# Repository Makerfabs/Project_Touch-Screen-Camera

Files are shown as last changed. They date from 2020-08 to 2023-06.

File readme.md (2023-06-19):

# ESP32 3.5" TFT Touch with Camera

```c++
/*
Version:		V6.2
Author:			Vincent
Create Date:	2020/8/19
Note:
	V6.2 : Change Wiki link.
	V6.1 : Update firmware add camera config faq.
	V6.0 : Add WiFi bulletin board demo
	V5.0 : Add Environment Expansion Board
	V4.1 : Add 1 show example.
	V4.0 : Add 4 show example.
	V3.4 : Thanks Lovyan03's change. Greatly speed up the rendering process.
	V3.3 : Change UI direction.
	V3.2 : Added the ability to upload photos to PC through WiFi. 
	V3.1 : Replace the picture with the new hardware.
	V3.0 : Delete many useless code. Add FAQ.
	V2.0 : Change ILI9488 driver,use LovyanGFX lib.Ten times faster than before!!!
	
*/
```
[ESP32 Touch Camera](https://www.youtube.com/watch?v=zWUy4gcwMs4&feature=youtu.be)

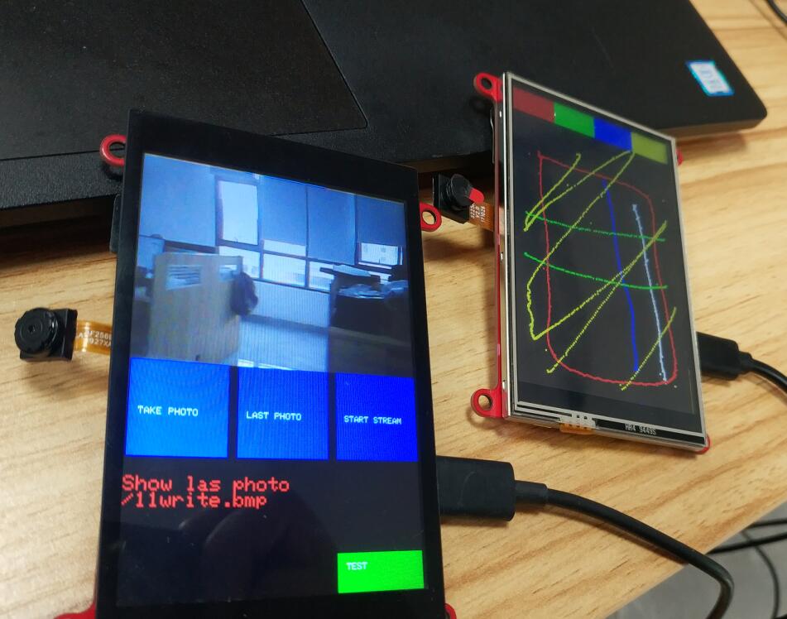
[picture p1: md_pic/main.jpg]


[toc]

# Makerfabs

[Makerfabs home page](https://www.makerfabs.com/)

[Makerfabs Wiki](https://wiki.makerfabs.com/)

# ESP32 3.5" TFT Touch with Camera

## Introduce

Product link ：[ ESP32 Touch Camera(Resistive)](https://www.makerfabs.com/esp32-3.5-inch-tft-touch-resistive-with-camera.html) 

Product link ：[ ESP32 Touch Camera(Capacitive)](https://www.makerfabs.com/esp32-3.5-inch-tft-touch-capacitive-with-camera.html) 

Wiki link ：[ESP32 3.5" TFT Touch with Camera](https://wiki.makerfabs.com/ESP32_3.5_TFT_Touch_with_Camera.html) 

The ESP32 Touch Camera use ILI9488 screen, which comes with resistive or capacitive screens. Have an OV2640 camera and SD card slot. It can be used as a webcam, an electronic album, or a digital camera. Support for Arduino and MicroPython. 

## Feature

- Integrated ESP32 2.4G WiFi and Bluetooth.
- Micro SD card slot on board.
- Input 5.0V Type-C USB .
- OV2640 is a 1/4 inch CMOS UXGA (1632*1232) image sensor manufactured by OmniVision.
- LCD 3.5 inch Amorphous-TFT-LCD (Thin Film Transistor Liquid Crystal Display) for mobile-phone or handy electrical equipments.
- NS2009 is A 4-wire resistive touch screen control circuit with I2C interface, which contains A 12-bit resolution A/D converter.

- The FT6X36 Series ICs are single-chip capacitive touch panel controller IC with a built-in 16 bit enhanced Micro-controller unit (MCU).

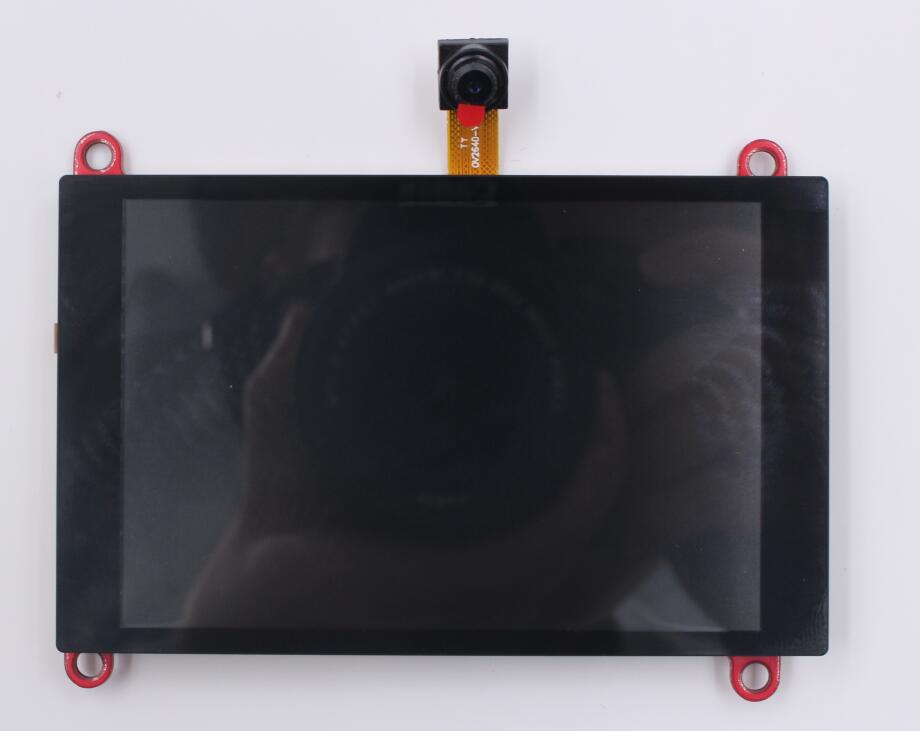
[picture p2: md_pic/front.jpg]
front


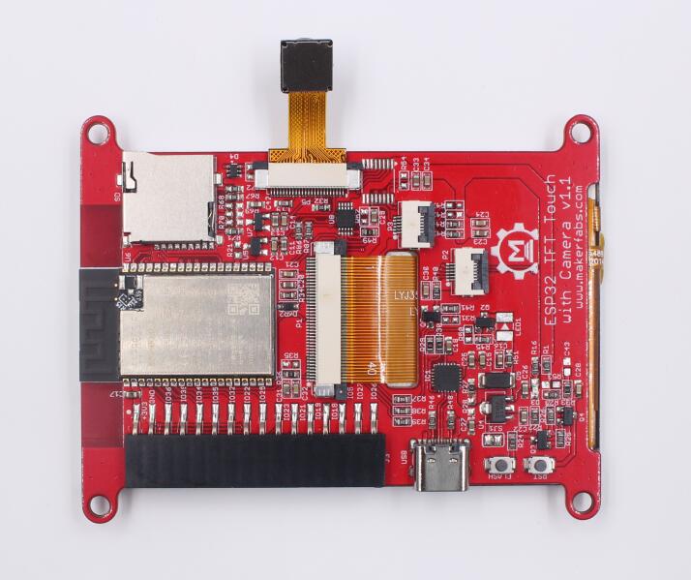
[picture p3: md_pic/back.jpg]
back


# Project

## Related projects

[ESP32 2048 GAME](https://github.com/Makerfabs/Project_ESP32-2048GAME)

Implement a 2048 game on "ESP32 Touch Camera". 

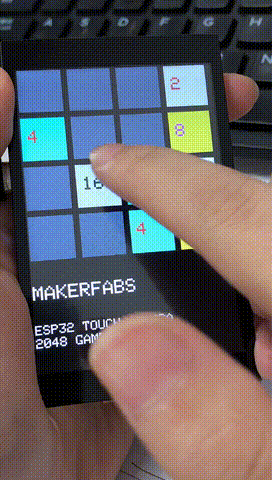
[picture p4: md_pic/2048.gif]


[ESP32 Flappy Bird](https://github.com/Makerfabs/Project_ESP32-Flappy-Bird)

Implement a Flappy Bird game on "ESP32 Touch Camera". 

Flappy

## Project introduction

Four projects were implemented : "Camera", "Touch_Draw", "SD2TFT" and "Receive WiFi Video".

### Camera_V2

- Take photos with OV2640 camera and preview in real-time on TFT screen.
- You can save photos to an SD card.
- Photos taken can be viewed through the TFT screen.

### Touch_Draw_V2

- Use your hand or stylus (resistance screen) to draw on the screen.

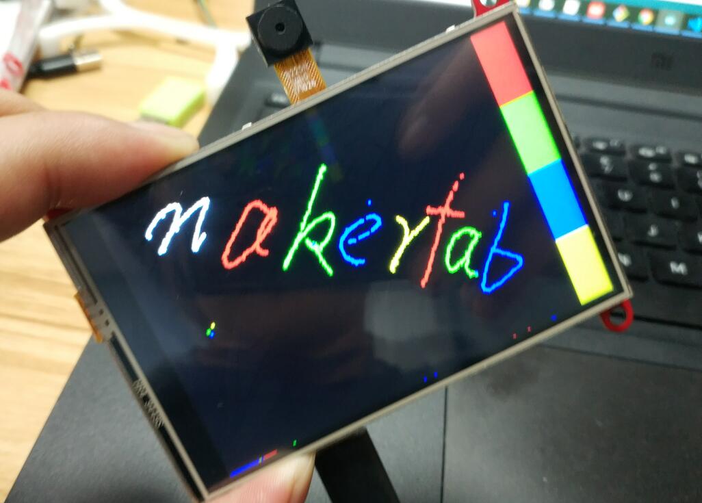
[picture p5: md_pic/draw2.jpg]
Touch_Draw_V2


### SD2TFT 

- Display pictures from SD card.
- Loop back the images in the SD card.

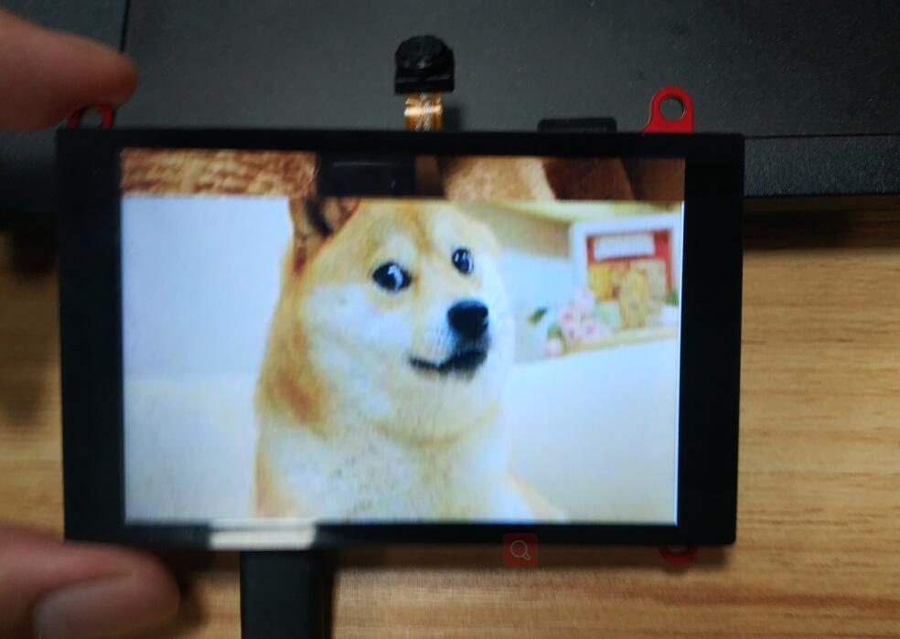
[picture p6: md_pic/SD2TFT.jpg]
SD2TFT


### Receive WiFi Video

Transmit the contents of the monitor to the TFT screen via Wifi.A host computer software is provided to box select the areas of the screen that need to be transferred.

Change from [MakePython ESP32 Color LCD で 動画をWiFi受信](https://homemadegarbage.com/makerfabs05)

- Upload file : "/Project_Touch-Screen-Camra/ESP32_ScreenShotReceiver-master/ScreenShotReceiver/ScreenShotReceiver.ino"
- Open "/Project_Touch-Screen-Camra/ESP32_ScreenShotReceiver-master/ScreenShotSender.exe"
- Input IP on the screen.

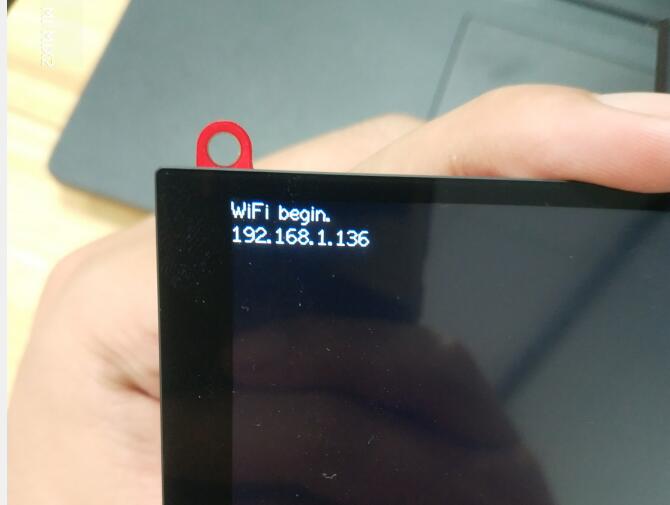
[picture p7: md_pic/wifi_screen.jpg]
wifiscreen


- Push connect.
- Start share your screen to TFT.

wifi_screen

## Compiler Options

**If you have any questions，such as how to install the development board, how to download the code, how to install the library. Please refer to :[Makerfabs_FAQ](https://github.com/Makerfabs/Makerfabs_FAQ)**

- Install board : ESP32 , select ESP32 version 1.0.6!!!!!!! After 2.0.0 version can't run successfully.
- **2022/4/28 Add：I don't know which libraries I updated, 1.0.6 compiles but doesn't drive the camera properly, rolling back the ESP32 version to 1.0.5 works fine.**
- Install library : LovyanGFX library. (SD2TFT is use a different GFX lib, depend on Adafruit_GFX. )
- Edit the code based on the touch screen. If you use resistive screen, choice NS2009_TOUCH. If you use capacitive screen, choice FT6236_TOUCH.

```c++
#define NS2009_TOUCH        //Resistive screen driver    
//#define FT6236_TOUCH      //Capacitive screen driver

#ifdef NS2009_TOUCH
#include "NS2009.h"
const int i2c_touch_addr = NS2009_ADDR;
#endif

#ifdef FT6236_TOUCH
#include "FT6236.h"
const int i2c_touch_addr = TOUCH_I2C_ADD;
#endif

```

- Upload codes, select "ESP32 Wrover Module" and "Huge APP"

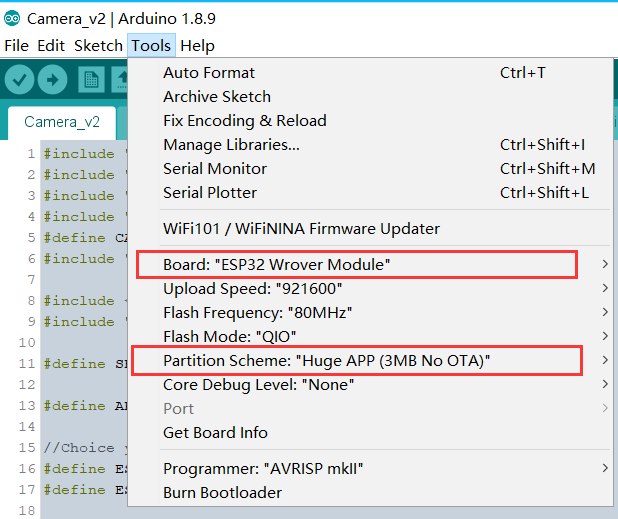
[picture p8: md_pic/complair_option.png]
complair-option


- Insert a Micro SD card into ESP32 Touch Camera.

## How To Use ESP32 Touch Camera

- Open the serial port monitor after uploading the code.
- Serial port will return initialization information, pay attention to see if there is any error.

```txt
14:48:49.096 -> ets Jun  8 2016 00:22:57
14:48:49.096 -> 
14:48:49.096 -> rst:0x1 (POWERON_RESET),boot:0x17 (SPI_FAST_FLASH_BOOT)
14:48:49.096 -> configsip: 0, SPIWP:0xee
14:48:49.096 -> clk_drv:0x00,q_drv:0x00,d_drv:0x00,cs0_drv:0x00,hd_drv:0x00,wp_drv:0x00
14:48:49.096 -> mode:DIO, clock div:1
14:48:49.096 -> load:0x3fff0018,len:4
14:48:49.096 -> load:0x3fff001c,len:1100
14:48:49.096 -> load:0x40078000,len:9232
14:48:49.096 -> load:0x40080400,len:6400
14:48:49.096 -> entry 0x400806a8
14:48:50.641 -> ILI9488 Test!
14:48:50.641 -> I2C device found at address 0x38  !
14:48:50.675 -> Card Mount Successed
14:48:50.675 -> SD init over.
14:48:51.397 -> TFT init over.
14:49:10.660 -> Image name：/0write.bmp
14:49:13.859 -> Image name：/1write.bmp

```

- If the SD card cannot be mounted on return, you need to re-insert the SD card.
- If everything is normal, the camera interface will be displayed.

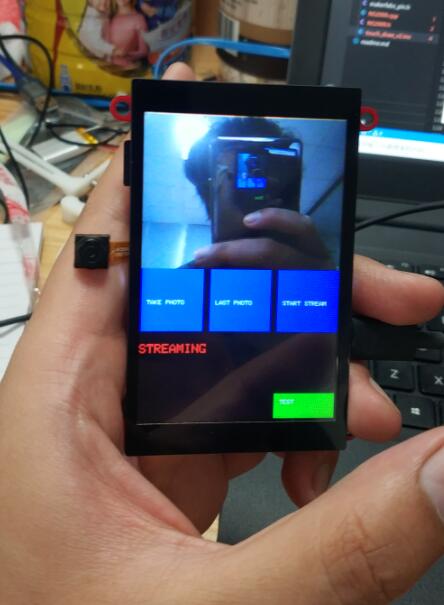
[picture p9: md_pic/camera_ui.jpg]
camera_ui


- Press the camera button to take photos automatically.
- Click on the previous photo to show the last photo saved on the SD card.

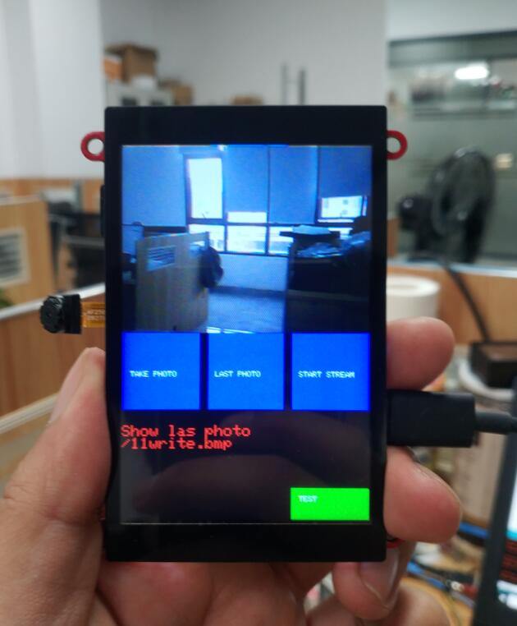
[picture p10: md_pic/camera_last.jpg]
camera_last


- Pressing to show the last photo will stop the camera acquisition. To restore the preview, press open Stream.
- Restore stream mode to take photos again.
- You can unplug your SD card and plug it into your computer to view your photos.

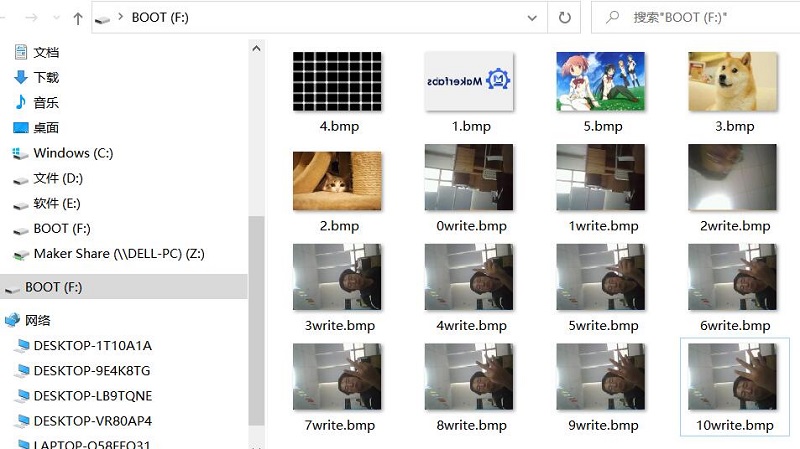
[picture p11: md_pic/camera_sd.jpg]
camera_sd


## V3.2 Upload photos via WiFi
Added the function of sending photos to PC via HTTP protocol by post method.
- Remove comments before WIFI_MODE

```c++
#define WIFI_MODE
```
- Set the wifi ssid and password.

```c++
// wait for WiFi connection
WiFi.mode(WIFI_STA);
WiFi.begin("Makerfabs", "20160704");
```
- Upload code to ESP32 camera.
- Run the server.py  on PC side.(Make sure to run in the directory server.py, otherwise the upload path cannot be found.)

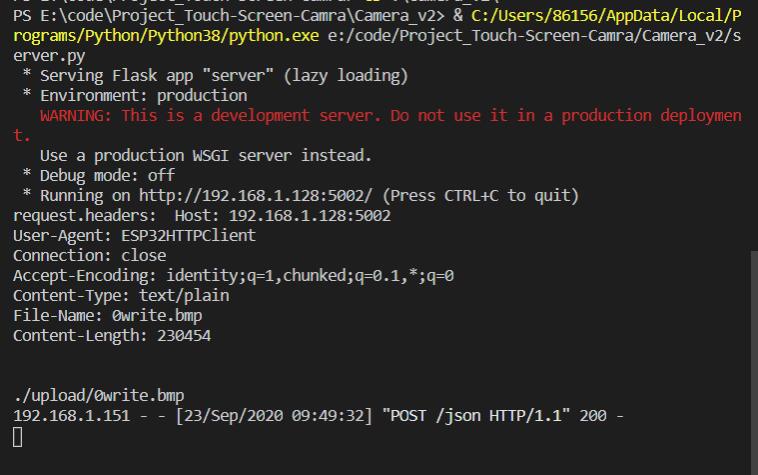
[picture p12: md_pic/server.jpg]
server

- Every time you click to show the last photo, it will be automatically uploaded.

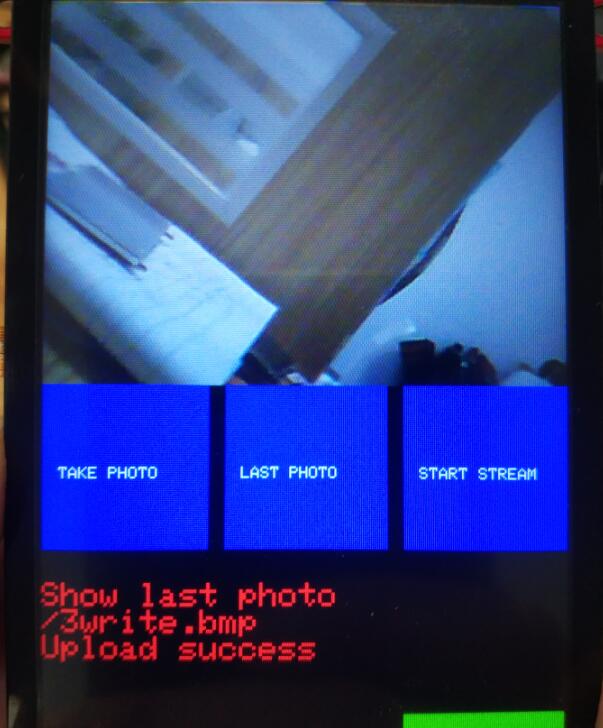
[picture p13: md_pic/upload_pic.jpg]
upload_pic

- In a few seconds, the picture will be uploaded to the Upload folder.
- V3.3  :  The UI has changed, but the functionality remains the same.

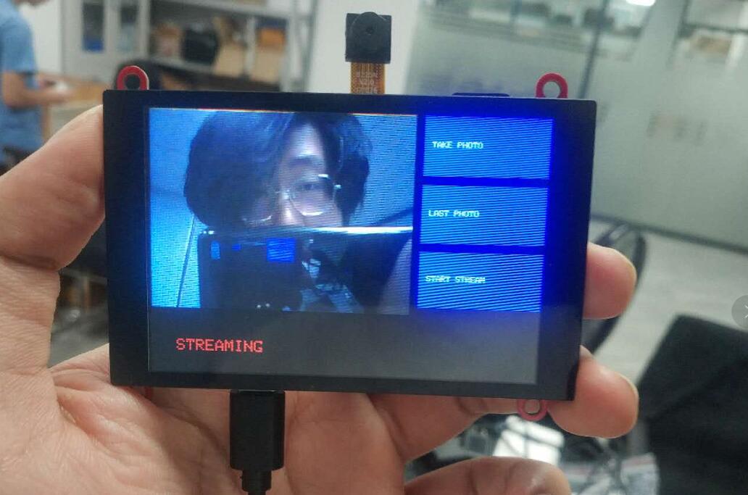
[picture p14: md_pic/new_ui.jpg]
new_ui


## V4.0 Show Example

Add 4 example in /Project_Touch-Screen-Camra/example

- Aht10 show
- HCSR04 meter
- Web button
- Wind speed show

These examples depend on TFT_eSPI library. You must set "User_Setup.h".
Set screen type.

```c++
// Only define one driver, the other ones must be commented out
//#define ILI9341_DRIVER
//#define ST7735_DRIVER      // Define additional parameters below for this display
//#define ILI9163_DRIVER     // Define additional parameters below for this display
//#define S6D02A1_DRIVER
//#define RPI_ILI9486_DRIVER // 20MHz maximum SPI
//#define HX8357D_DRIVER
//#define ILI9481_DRIVER
//#define ILI9486_DRIVER
#define ILI9488_DRIVER     // WARNING: Do not connect ILI9488 display SDO to MISO if other devices share the SPI bus (TFT SDO does NOT tristate when CS is high)
//#define ST7789_DRIVER      // Full configuration option, define additional parameters below for this display
//#define ST7789_2_DRIVER    // Minimal configuration option, define additional parameters below for this display

// For ST7789, ST7735, ILI9163 and GC9A01 ONLY, define the pixel width and height in portrait orientation
// #define TFT_WIDTH  80
// #define TFT_WIDTH  128
// #define TFT_WIDTH  172 // ST7789 172 x 320
//#define TFT_WIDTH  240 // ST7789 240 x 240 and 240 x 320
#define TFT_WIDTH  320
// #define TFT_HEIGHT 160
// #define TFT_HEIGHT 128
// #define TFT_HEIGHT 240 // ST7789 240 x 240
// #define TFT_HEIGHT 320 // ST7789 240 x 320
//#define TFT_HEIGHT 240 // GC9A01 240 x 240
#define TFT_HEIGHT 480

```
And set pins.

```c++
// For 3.5" 9488
// The hardware SPI can be mapped to any pins

#define TFT_MISO 12
#define TFT_MOSI 13
#define TFT_SCLK 14
#define TFT_CS   15  // Chip select control pin
#define TFT_DC    33  // Data Command control pin
#define TFT_RST   26  // Reset pin (could connect to RST pin)

```

## V4.1 Show Example

Add environment monitoring module demo.

- Line chart

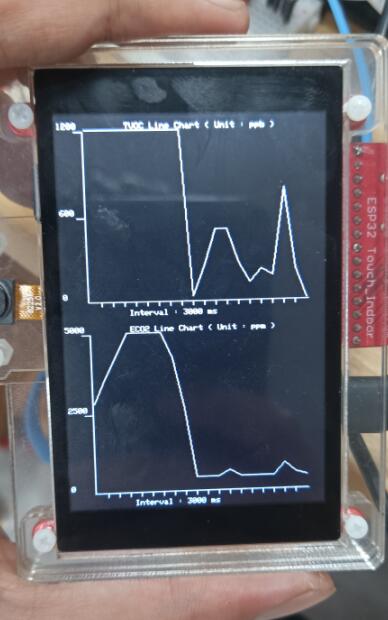
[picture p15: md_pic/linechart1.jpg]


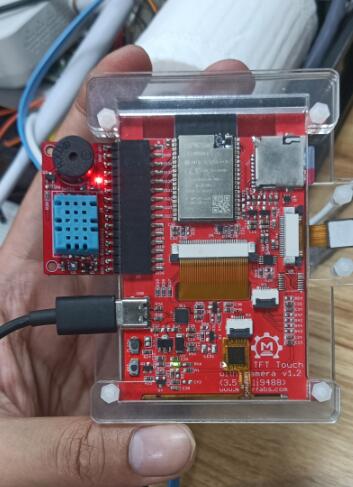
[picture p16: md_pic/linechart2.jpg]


## V6.0 WiFi bulletin board Demo

Added a WiFi bulletin board app. You can upload and browse files in the SD card through the web page. And the latest uploaded BMP or TXT display on the 3.5-inch screen.

- Library Install：[esp32-micro-sdcard](https://github.com/nhatuan84/esp32-micro-sdcard) and [esp32-webserver](https://github.com/nhatuan84/esp32-webserver)
- Upload .\example\wifi_img\wifi_img.ino
- Insert the SD card and power on.
- Enter the IP address on the screen in your browser.

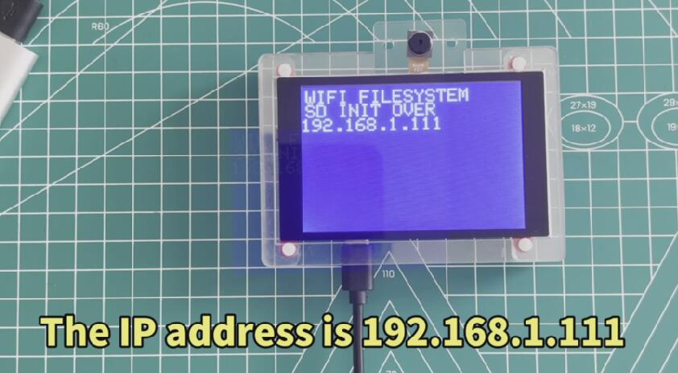
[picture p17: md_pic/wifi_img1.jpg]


- Select TXT or BMP to be uploaded. BMP must be 480 x 320 pixels, 24 bits.

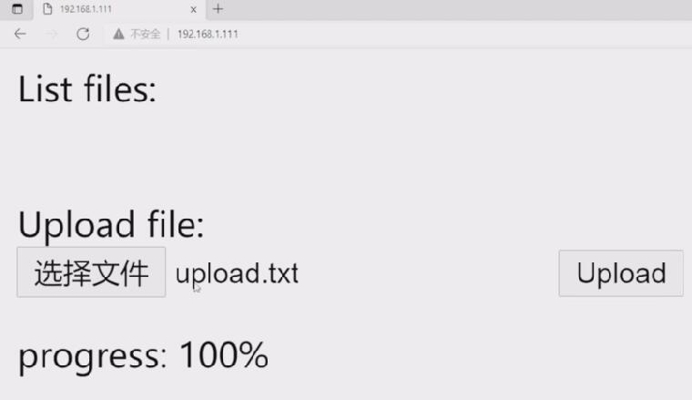
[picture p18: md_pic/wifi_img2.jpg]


- Upload.
- Wait seconds, the content is displayed on the screen.

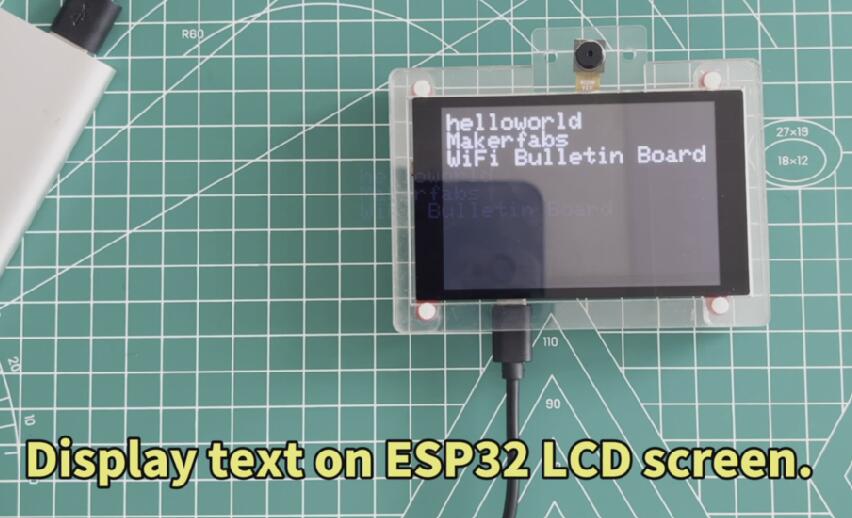
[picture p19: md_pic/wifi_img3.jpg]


## FAQ

### Q: Can't Upload!

A: Switch to a good USB cable. Poor USB cable quality can cause ESP32 to reboot or fail to upload. Open the serial monitor, observe serial port information.

### Q: The screen is white!

A: The SD card was not mounted successfully, so the program goes into an endless loop. Re-insert the SD card and restart it. Open the serial monitor,  The serial port will display the work log.

### Q: It doesn't show the picture that was just taken!

A: It may be that after shooting, the SD card was not in good contact, so it could not be stored in the SD card. Playback photos are read inside the SD card photos. Re-insert the SD card and restart it.

### Q: Other questions...

A: Re-insert the SD card and restart it. Can solve most problems. (laugh)

### Q: Camera direction wrong

A: Depending on the batch of purchased cameras, the picture may be inverted. You can configure the following functions.

Change set_vflip() param to flip camera or set_hmirror() to mirror image.

```c++
// Camera setting
void camera_init()
{
    // camera config
    
    //...

    sensor_t *s = esp_camera_sensor_get();
    // initial sensors are flipped vertically and colors are a bit saturated
    if (s->id.PID == OV2640_PID)
    {
        s->set_vflip(s, 0);   // vertical flip
        s->set_hmirror(s, 0); // Horizontal mirror

        s->set_brightness(s, 0); // up the blightness just a bit
        s->set_saturation(s, 1); // lower the saturation
    }
    // drop down frame size for higher initial frame rate
    s->set_framesize(s, FRAMESIZE_QVGA);

    show_log(2);
}
```

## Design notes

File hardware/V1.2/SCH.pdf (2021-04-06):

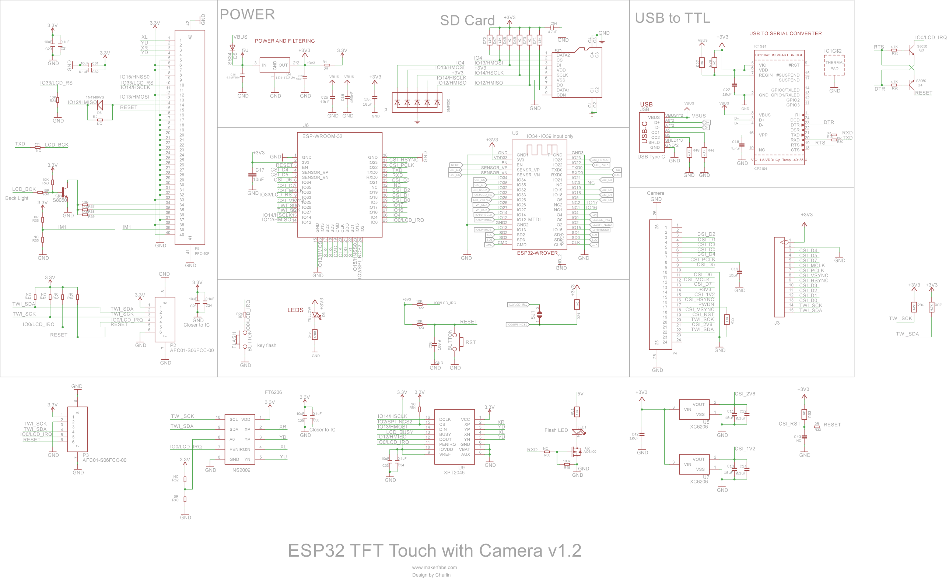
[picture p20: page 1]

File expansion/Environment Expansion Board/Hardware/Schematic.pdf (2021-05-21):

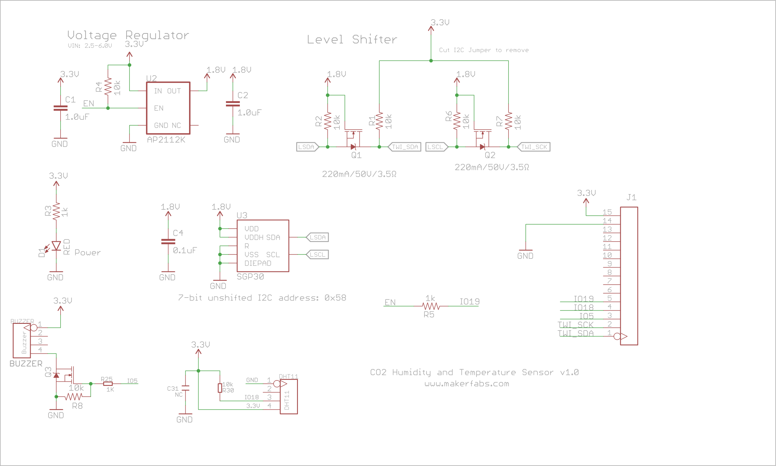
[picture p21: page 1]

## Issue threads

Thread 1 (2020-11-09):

How to buy products in China?

modi12jin, 2020-11-09:
Ask about non-technical topics, how can China buy your products?

Makerfabs, 2020-11-10:
Please contact sales: zeqing2012@makerfabs.com

发件人: modi12jin [mailto:notifications@github.com]
发送时间: 2020年11月9日 19:23
收件人: Makerfabs/Project_Touch-Screen-Camera
抄送: Subscribed
主题: [Makerfabs/Project_Touch-Screen-Camera] How to buy products in China? (#1)

Ask about non-technical topics, how can China buy your products?

—
You are receiving this because you are subscribed to this thread.
Reply to this email directly, view it on GitHub <https://github.com/Makerfabs/Project_Touch-Screen-Camera/issues/1> , or unsubscribe <https://github.com/notifications/unsubscribe-auth/AHZNOCDI57JW5QYPGHIKBLTSO7GKBANCNFSM4TPGWWTA> .图像已被发件人删除。

Closed 2021-07-02.

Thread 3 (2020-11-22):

The Camera Module or Code does not work

JJSlabbert, 2020-11-22:
I get the following error when I compile the Camera_v2.ino

I have the capacitive screen

spi_host_device_t' does not name a type

Makerfabs, 2021-09-14:
@JJSlabbert  Hi, can you post a logcat for your issuse? May be you can update your SPI library.

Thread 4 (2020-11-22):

Board dimensions please

markandkymward, 2020-11-22:
Where can I get a detail dimensional drawing.  I am designing a case while I wait for the product to ship

195cn, 2021-01-12:
We put pcb file in directory [hardware](https://github.com/Makerfabs/Project_Touch-Screen-Camera/tree/master/hardware/v1.1).

Closed 2021-01-12.

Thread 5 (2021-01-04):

SCL and SDA pinout

gigwegbe, 2021-01-04:
Hello Makerfabs,
I have been trying to interface with an accelerator(MPU-6050) and so far I can't identify the SCL and SDA pins on the board(ESP32 TFT capacitive screen). Please kindly specify them. Thanks.

195cn, 2021-01-12:
ESP32 can use any pins as I2C pins. Such like:

`Wire.begin(MAKEPYTHON_ESP32_SDA, MAKEPYTHON_ESP32_SCL);`

Closed 2021-01-12.

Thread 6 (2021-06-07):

3D printed case?

JanHBade, 2021-06-07:
Hello,

I am looking for something like this one:
https://www.thingiverse.com/thing:4661069

JanHBade, 2021-06-15:
https://www.thingiverse.com/thing:4886441

make my own

Closed 2021-06-15.

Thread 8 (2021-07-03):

Backlight Control

fvanroie, 2021-07-03:
Does the board have a way to control the backlight brightness via GPIO?

I see in the schematic:
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

Do I need to solder TXD to LCD_BCK on the board?

Makerfabs, 2021-09-14:
@fvanroie Yes, as you can see from the schematic(https://github.com/Makerfabs/Project_Touch-Screen-Camera/tree/master/hardware/ ) , all the pins are connected to camera/LCD/SD card, there only TXD/RXD left.  If you want to control the backlight,  solder R31(0R,0603) resistance on the board and set TXD as GPIO1 for PWM output(You can't see the uart  debug message any more).
   Generally speaking, if you had finished your code after a lot of testing. The released firmware didn't need debug message any more, so you can set TXD pin as PWM output pin to control backlight.

FrancisGut, 2021-12-14:
Hello, I just soldered the R31 resistance and I want to control the tft brightness in Arduino but I dont find the way to do it. Have you some comments about it, please? Thanks.

FrancisGut, 2021-12-16:
Hello, the problem is solved. Sorry I have setted the pin 35 as TXD but is the GPIO1, so the pin to write the analog values is the 1. Thanks.

mmccool, 2022-05-09:
This is great to know.  I wanted to use this board with openHASP but the lack of backlight control is a big problem for a home control panel.  I don't care about TX so... and I guess technically I don't even need a resistor, I can just bridge the two pads with a blob of solder.  But now I need to hack the openHASP code to understand it needs to use GPIO1 :)

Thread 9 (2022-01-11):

Detected camera not supported

citizenanalog, 2022-01-11:
I'm running Camera_v2 and monitoring serial port after upload results in:

ILI9488 Test!
I2C device found at address 0x38  !
Card Mount Successed
SD init over.
TFT init over.
[E][camera.c:1113] camera_probe(): Detected camera not supported.
[E][camera.c:1379] esp_camera_init(): Camera probe failed with error 0x20004

Any suggestions?

citizenanalog, 2022-01-12:
I'm guessing it's a bad camera module...

195cn, 2022-01-13:
Yes.
The camera is probably broken
If reinstalling the camera still results in this, it should be damaged.
The camera code was moved directly from the ESP-CAM project, and I'm not very familiar with the error.

citizenanalog, 2022-01-13:
Thanks for the feedback!

citizenanalog, 2022-01-16:
Tried a brand new camera and still getting the same error :(

195cn, 2022-01-17:
What is the version of your ESP32 library? 1.0.6 was used for development.
Versions later than 2.0 proved unable to load the SD library properly. There may be other problems.

citizenanalog, 2022-01-17:
I'm using esp32 v 1.0.6

citizenanalog, 2022-01-18:
Downgrade to esp32 v 1.0.4 and it works! Seems like an issue with the newer version for me anyway.

Closed 2022-01-13.

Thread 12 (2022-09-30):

Unable to import .sch and .brd hardware files

5ensors, 2022-09-30:
I have attempted to import the hardware design files for this project to understand the operation and PCB layout, but all my attempts to open it have failed. I have tried to import into Altium Design and also EasyEDA, which previously had no issues importing Eagle design files.

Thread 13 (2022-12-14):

ScreenShotSender.exe found with a virus.

gz-jgale, 2022-12-14:
<html xmlns:o="urn:schemas-microsoft-com:office:office"
xmlns:dt="uuid:C2F41010-65B3-11d1-A29F-00AA00C14882"
xmlns="http://www.w3.org/TR/REC-html40">

<head>

<meta name=ProgId content=OneNote.File>
<meta name=Generator content="Microsoft OneNote 15">
</head>

<body lang=en-US style='font-family:Calibri;font-size:11.0pt'>
<!--StartFragment-->

<div style='direction:ltr'>

Date/Time | Infected File/Object | Security Threat | Result | Scan Type | File Path
-- | -- | -- | -- | -- | --
12/14/2022 (Wed) 1:20 | ScreenShotSender.exe | TROJ_GEN.R002C0PL422 | Cleaned | Scheduled Scan | C:\Users\gz-jgale\Makerfabs_ESPTFT35CA\Project_Touch-Screen-Camera-master\Project_Touch-Screen-Camera-master\example\ESP32_ScreenShotReceiver-master\

</div>

<!--EndFragment-->
</body>

</html>

lovyan03, 2022-12-19:
Executable files containing communication functions are relatively easy to be misidentified as viruses.
The source code is disclosed, so you can build it yourself.

gz-jgale, 2024-03-15:
@lovyan03,

You may have had a virus that got in at compile time and made it into the compiled exe that is saved in the repo assets that does not represent the source code intentions. This was flagged again in my company IT scans when I downloaded the files again.

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

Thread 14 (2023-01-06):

Pin 26 and Pin 27 Hardwired to SDA and SCL

agalgano08, 2023-01-06:
I need Pin 26,27 for a two wire motor running off a motor controller and I need it also for I2C to communicate with the touchscreen as it is hard wired in. Each works separately perfectly, but when I try and end the Wire and move the motor, nothing happens and no error is thrown.

Motor is custom class that uses ledc and works when the motor code is above the Wire setup code.

Is there a way to disable the I2C with the screen shortly disabling the screen touch feature and use the motor without interferance?

```
  Motor m1 = Motor(26, 27, 1);

  Wire.begin(26, 27);
  Serial.println("Wire Begin");

  int XL = 0;
  int XH = 0;
  int YL = 0;
  int YH = 0;

  int data = 0;
  Wire.beginTransmission(TOUCH_I2C_ADD);
  Wire.write(TOUCH_REG_XH);
  Wire.endTransmission();
  Wire.requestFrom(TOUCH_I2C_ADD, 1);

  if (Wire.available())
  {
    data = Wire.read();
  }
  XH = data;
  Wire.end();
  Serial.println("Wire End");

  m1.Move(100, HIGH);
  delay(1000);
  m1.Move(0, HIGH);
  delay(1000);
```

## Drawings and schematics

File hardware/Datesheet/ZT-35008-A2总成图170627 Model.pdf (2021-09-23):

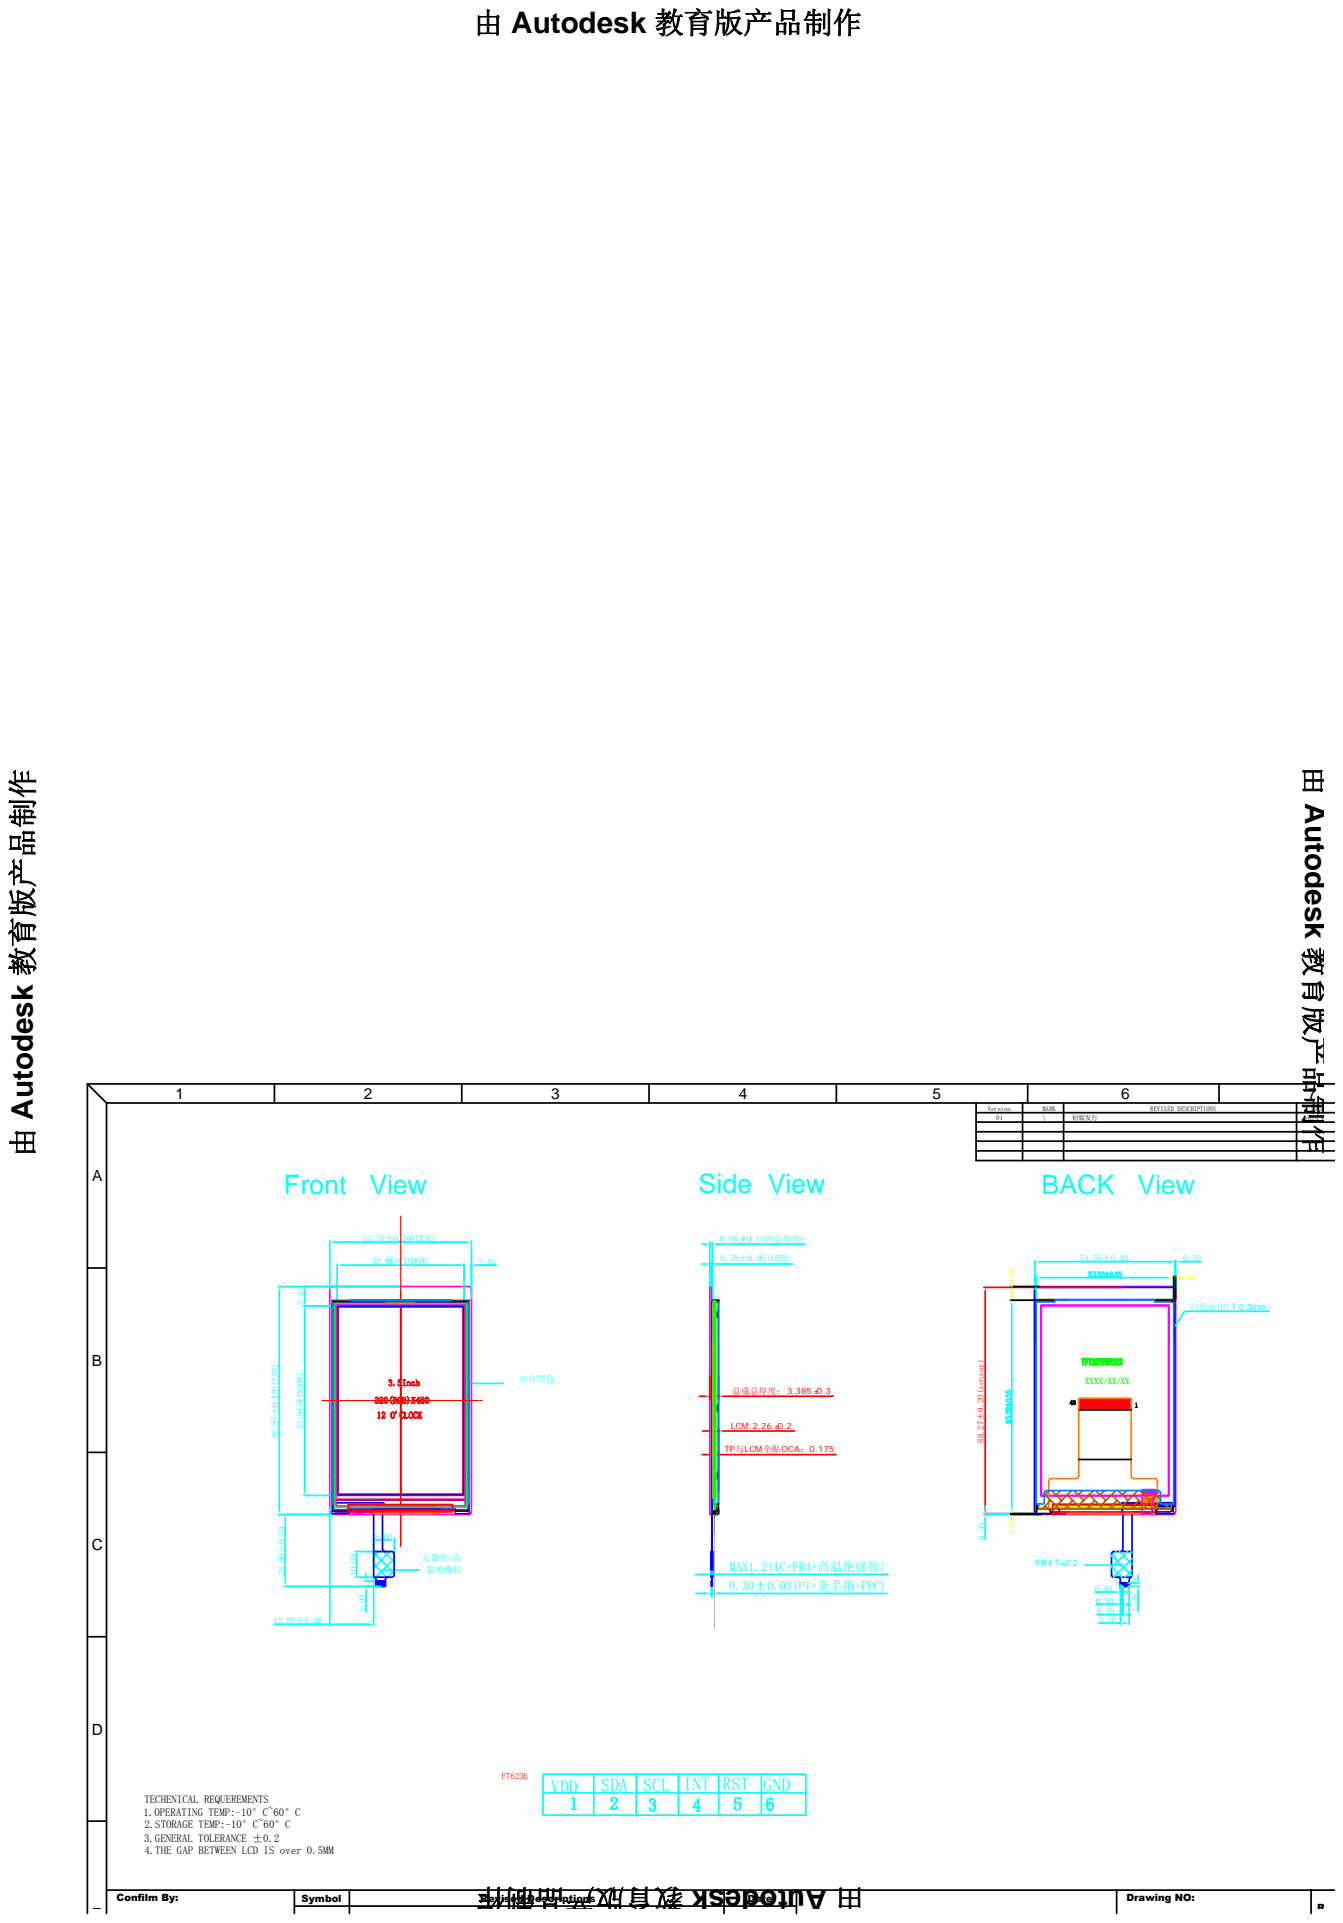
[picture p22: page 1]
Front View; Side View; Revised Descriptions; Date; Confilm By:; Symbol; Drawing NO:; BACK View; Version; MARK; REVISED DESCRIPTIONS; DATE; 88.27±0.20(sensor) 0.30; LCM:2.26 ±0.2; 总成总厚度： 3.385±0.3; 由 Autodesk 教育版产品制作

01 | \ | 初版发行 | 2015-04-

XXXX/XX/XX

MAX1.2(IC+FR4+高温绝缘胶)
0.30±0.03(PI+金手指+FPC)

TECHENICAL REQUEREMENTS
1.OPERATING TEMP:-10°C~60°C
2.STORAGE TEMP:-10°C~60°C
3.GENERAL TOLERANCE ±0.2
4.THE GAP BETWEEN LCD IS over 0.5MM

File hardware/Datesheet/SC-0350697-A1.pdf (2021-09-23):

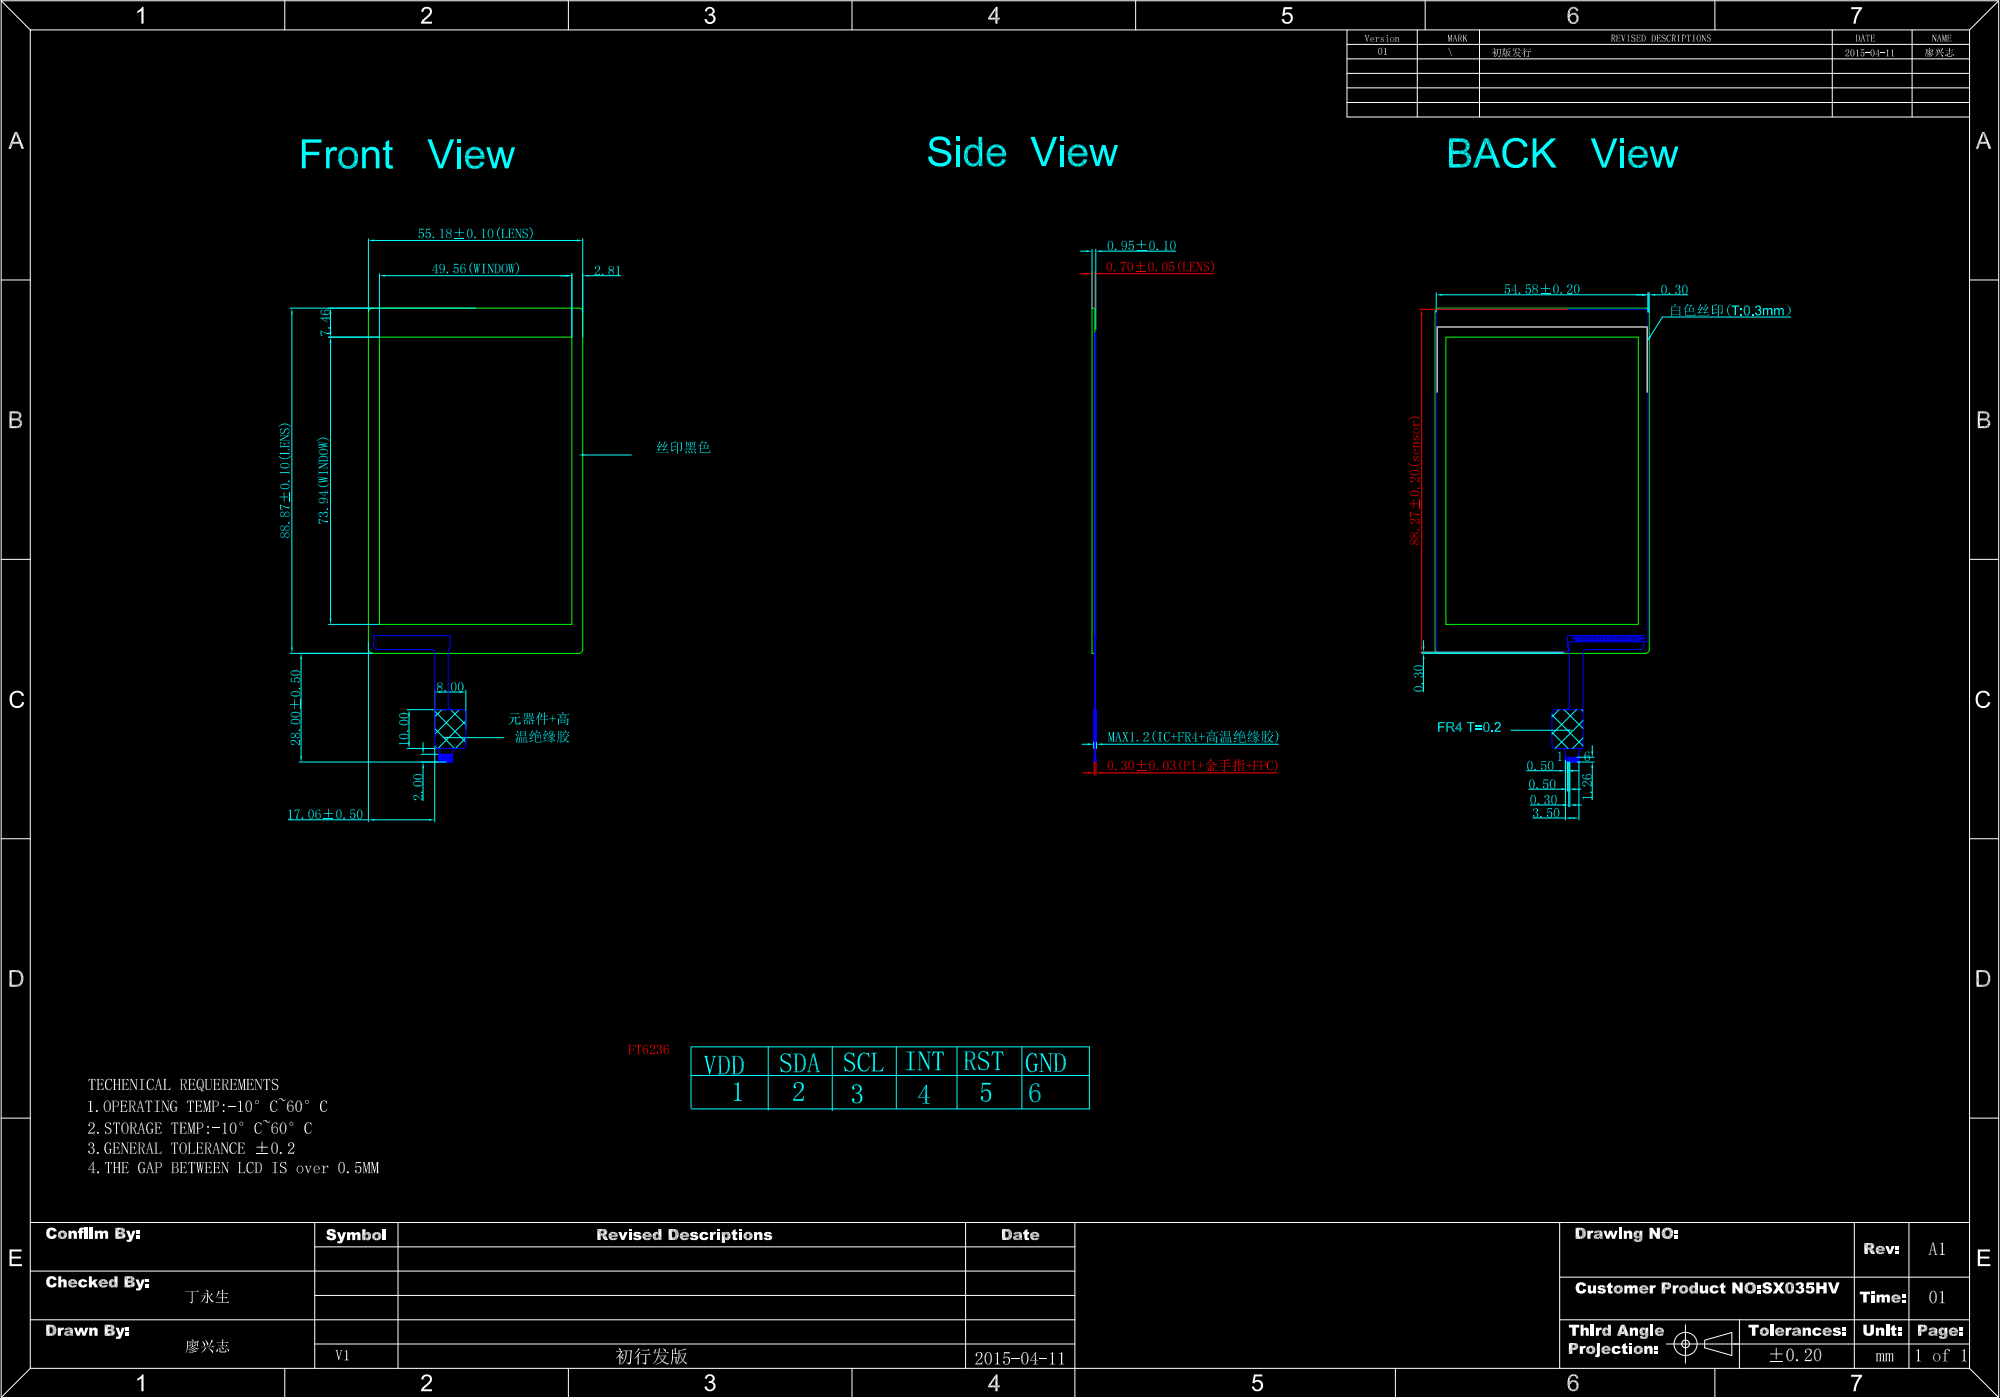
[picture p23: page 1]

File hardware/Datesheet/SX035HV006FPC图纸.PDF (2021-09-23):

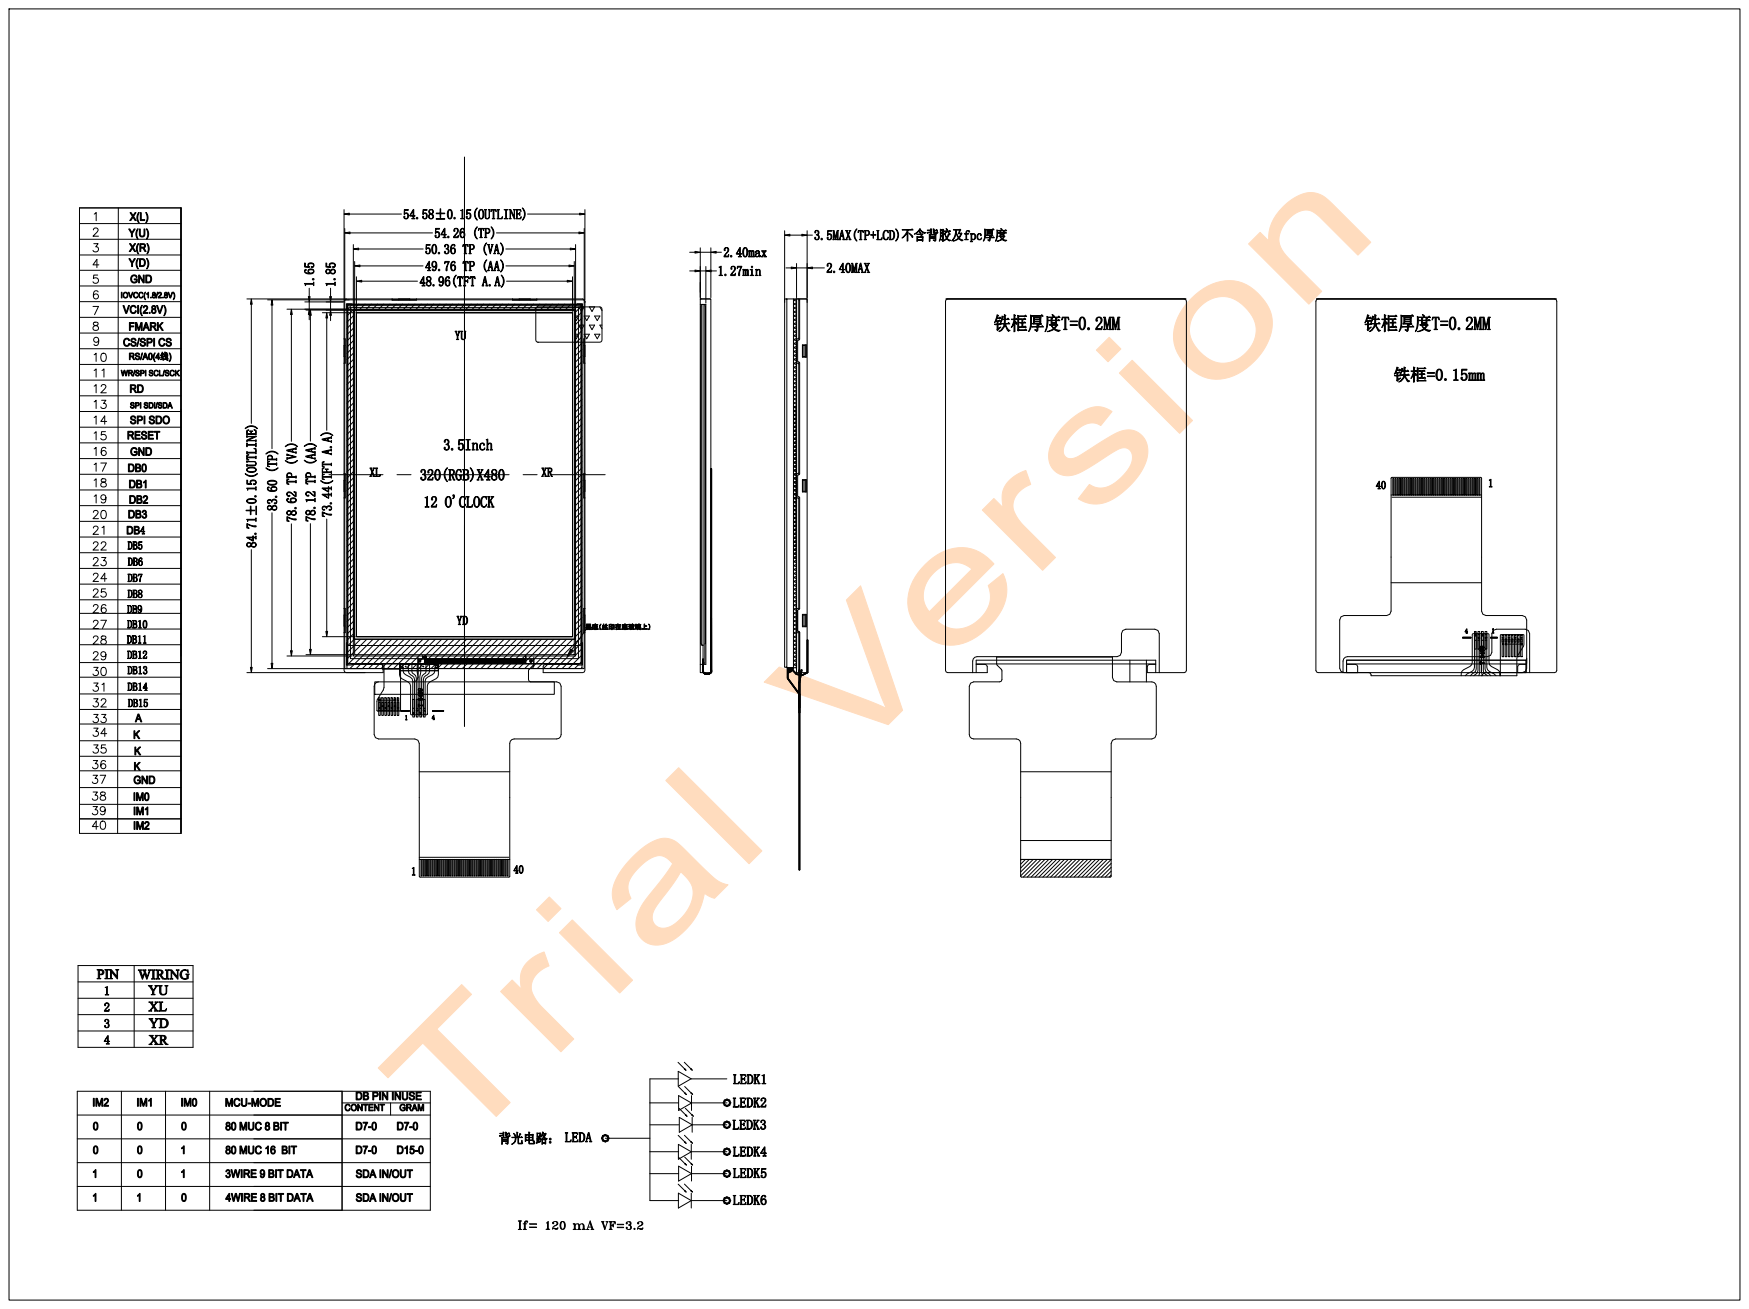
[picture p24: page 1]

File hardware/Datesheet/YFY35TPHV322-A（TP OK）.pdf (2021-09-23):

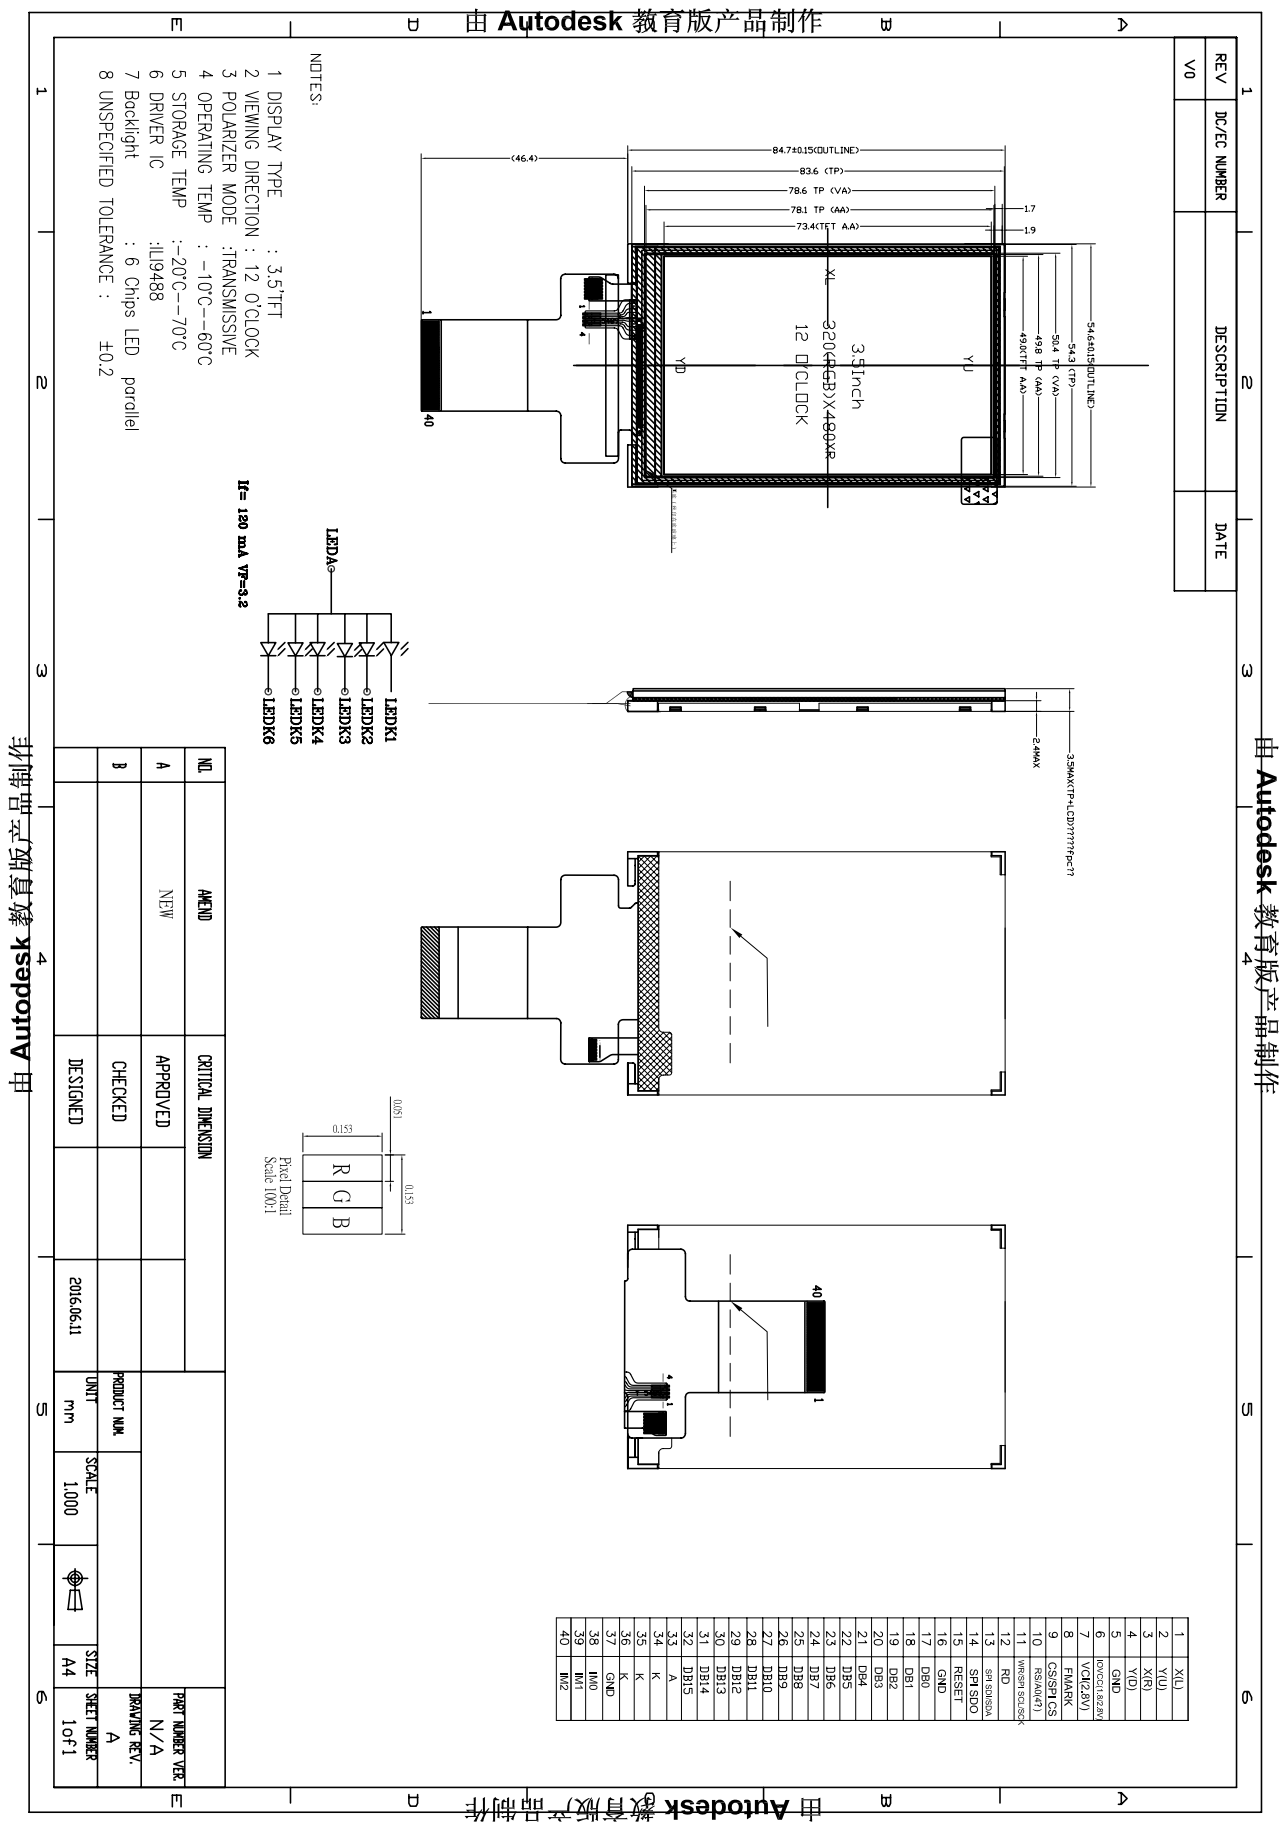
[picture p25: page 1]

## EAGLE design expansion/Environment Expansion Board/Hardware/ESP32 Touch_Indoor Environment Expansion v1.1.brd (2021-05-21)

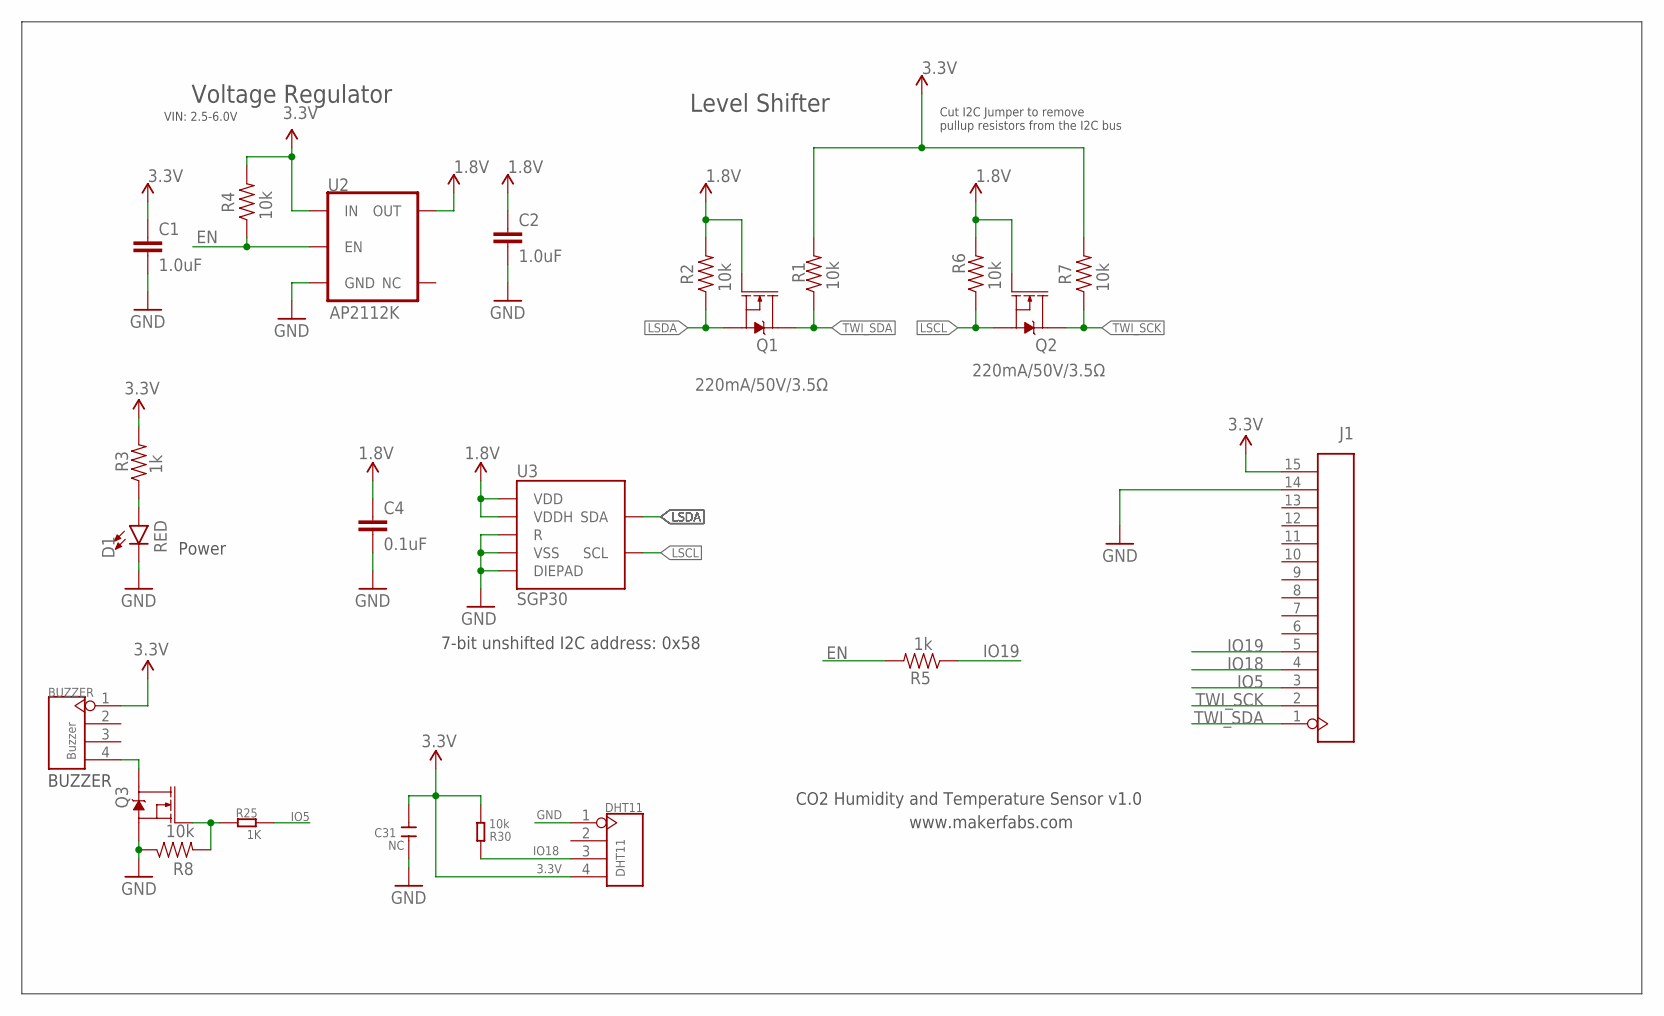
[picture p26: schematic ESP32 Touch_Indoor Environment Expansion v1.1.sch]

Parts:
BUZZER: Buzzer; 4P-65/35ROUND
C1, C2: 1.0uF; 0603
C4: 0.1uF; 0603
C31: NC; 0603
D1: RED; LED-0603
DHT11: DHT11; 4P-65/35ROUND
J1: HEADER-1X15P3; DIP-1X15-2.54MM-W
Q1, Q2, Q3: 220mA/50V/3.5Ω; SOT23-3
R1, R2, R4, R6, R7, R8: 10k; 0603
R3, R5: 1k; 0603
R25: 1K; R0603
R30: 10k; R0603
U2: AP2112K; SOT23-5
U3: SGP30

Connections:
1.8V: C2.1, C4.1, Q1.1 (G), Q2.1 (G), R2.2, R6.2, U2.5 (OUT), U3.1 (VDD), U3.5 (VDDH)
3.3V: BUZZER.1, C1.1, C31.2, DHT11.4, J1.15, R1.2, R3.2, R4.2, R7.2, R30.2, U2.1 (IN)
EN: R4.1, R5.2, U2.3 (EN)
GND: C1.2, C2.2, C4.2, C31.1, D1.C, DHT11.1, J1.14, Q3.2 (S), R8.1, U2.2 (GND), U3.2 (VSS), U3.4 (R), U3.DIEPAD
IO5: J1.3, R25.1
IO18: DHT11.3, J1.4, R30.1
IO19: J1.5, R5.1
LSCL: Q2.2 (S), R6.1, U3.6 (SCL)
LSDA: Q1.2 (S), R2.1, U3.3 (SDA)
unnamed: BUZZER.4, Q3.3 (D)
unnamed: Q3.1 (G), R8.2, R25.2
unnamed: D1.A, R3.1
TWI_SCK: J1.2, Q2.3 (D), R7.1
TWI_SDA: J1.1, Q1.3 (D), R1.1

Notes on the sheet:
Voltage Regulator
VIN: 2.5-6.0V
Cut I2C Jumper to remove pullup resistors from the I2C bus
Power
7-bit unshifted I2C address: 0x58
CO2 Humidity and Temperature Sensor v1.0
www.makerfabs.com
Level Shifter
BUZZER

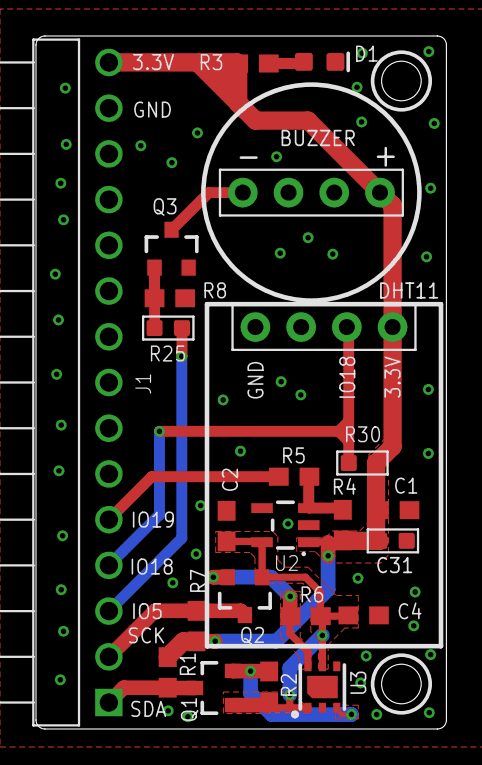
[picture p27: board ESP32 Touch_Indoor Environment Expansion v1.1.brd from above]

Board: 2 copper layers, 22.8 x 38.5 mm, 24 parts (1 on the bottom side), 14 nets.

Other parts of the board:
U$1: MAKERFABS_0.3

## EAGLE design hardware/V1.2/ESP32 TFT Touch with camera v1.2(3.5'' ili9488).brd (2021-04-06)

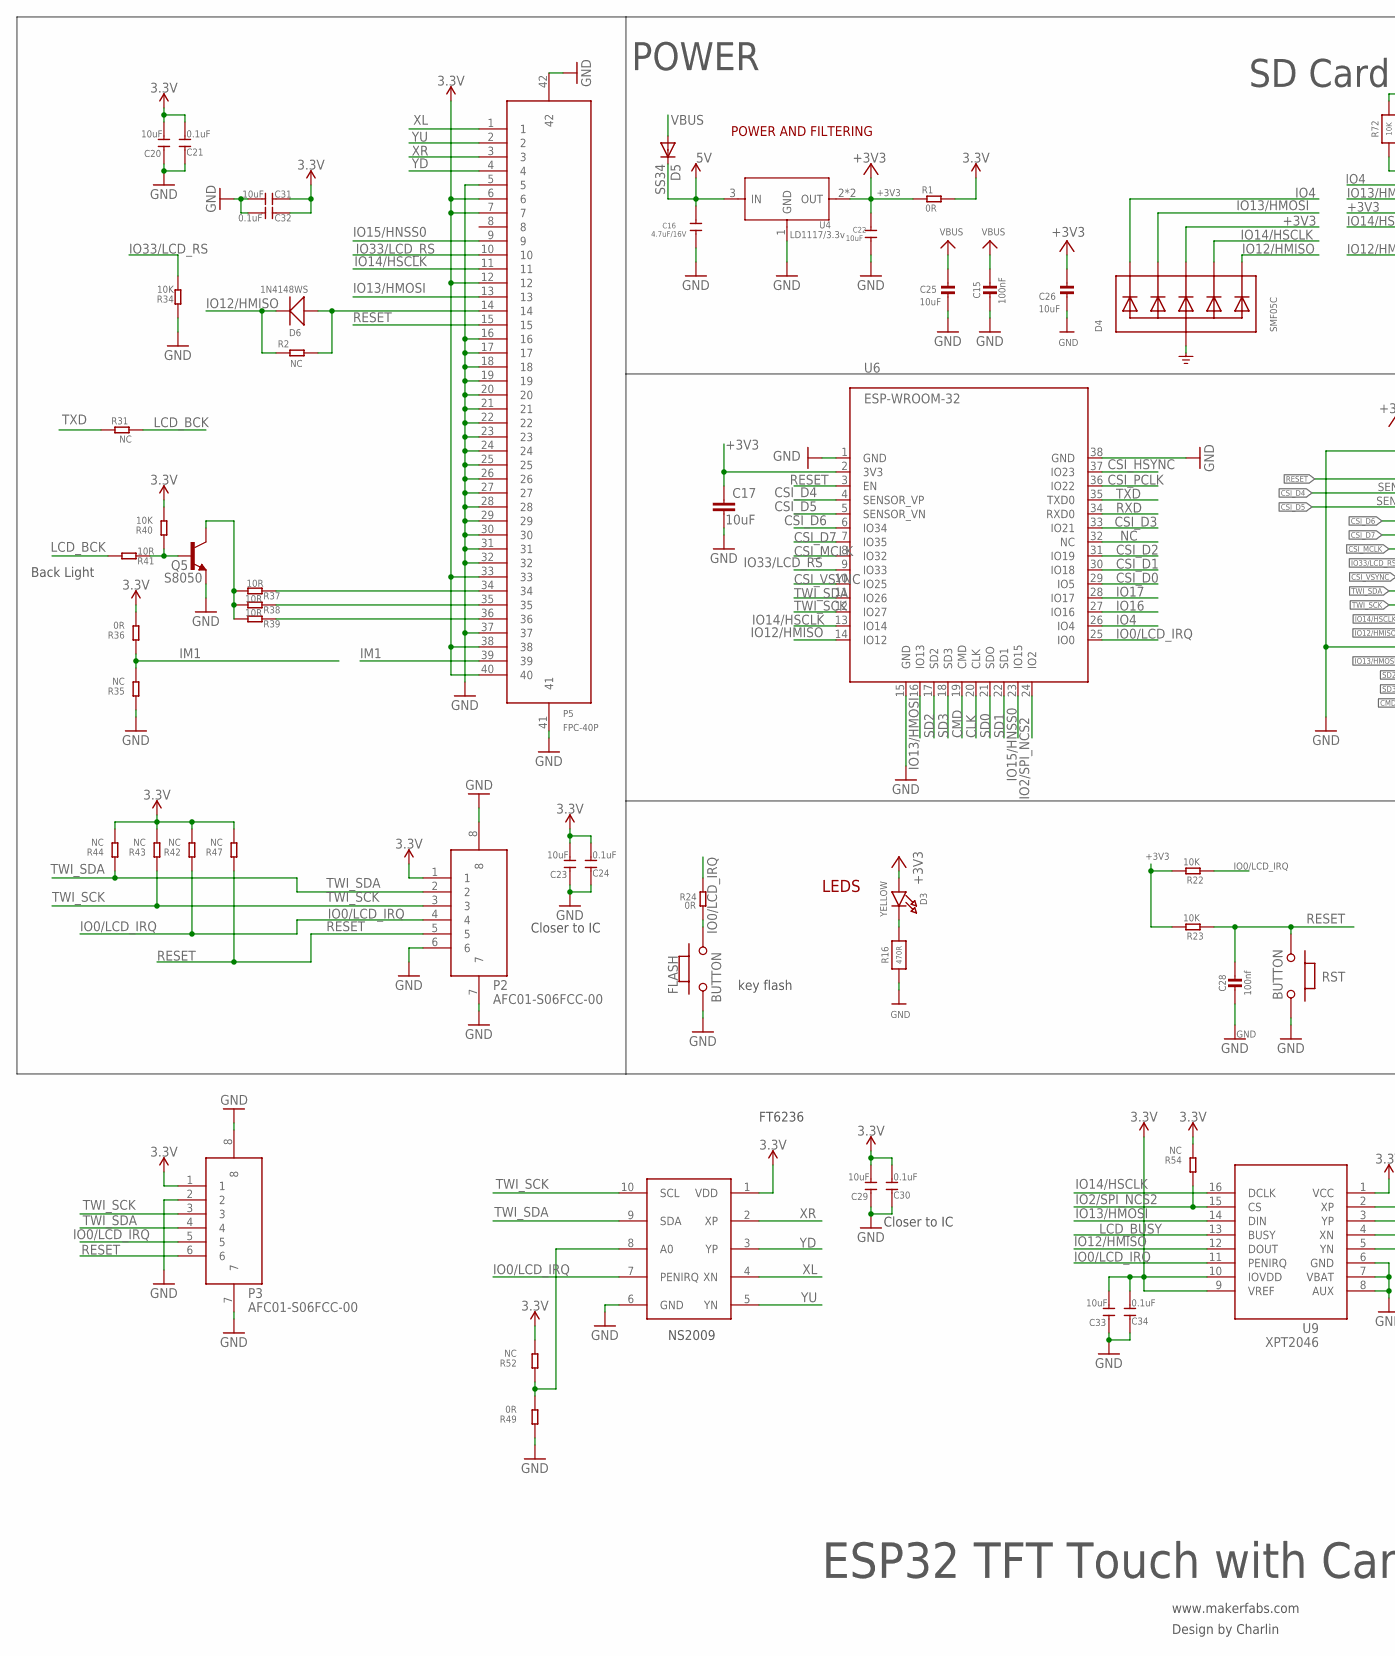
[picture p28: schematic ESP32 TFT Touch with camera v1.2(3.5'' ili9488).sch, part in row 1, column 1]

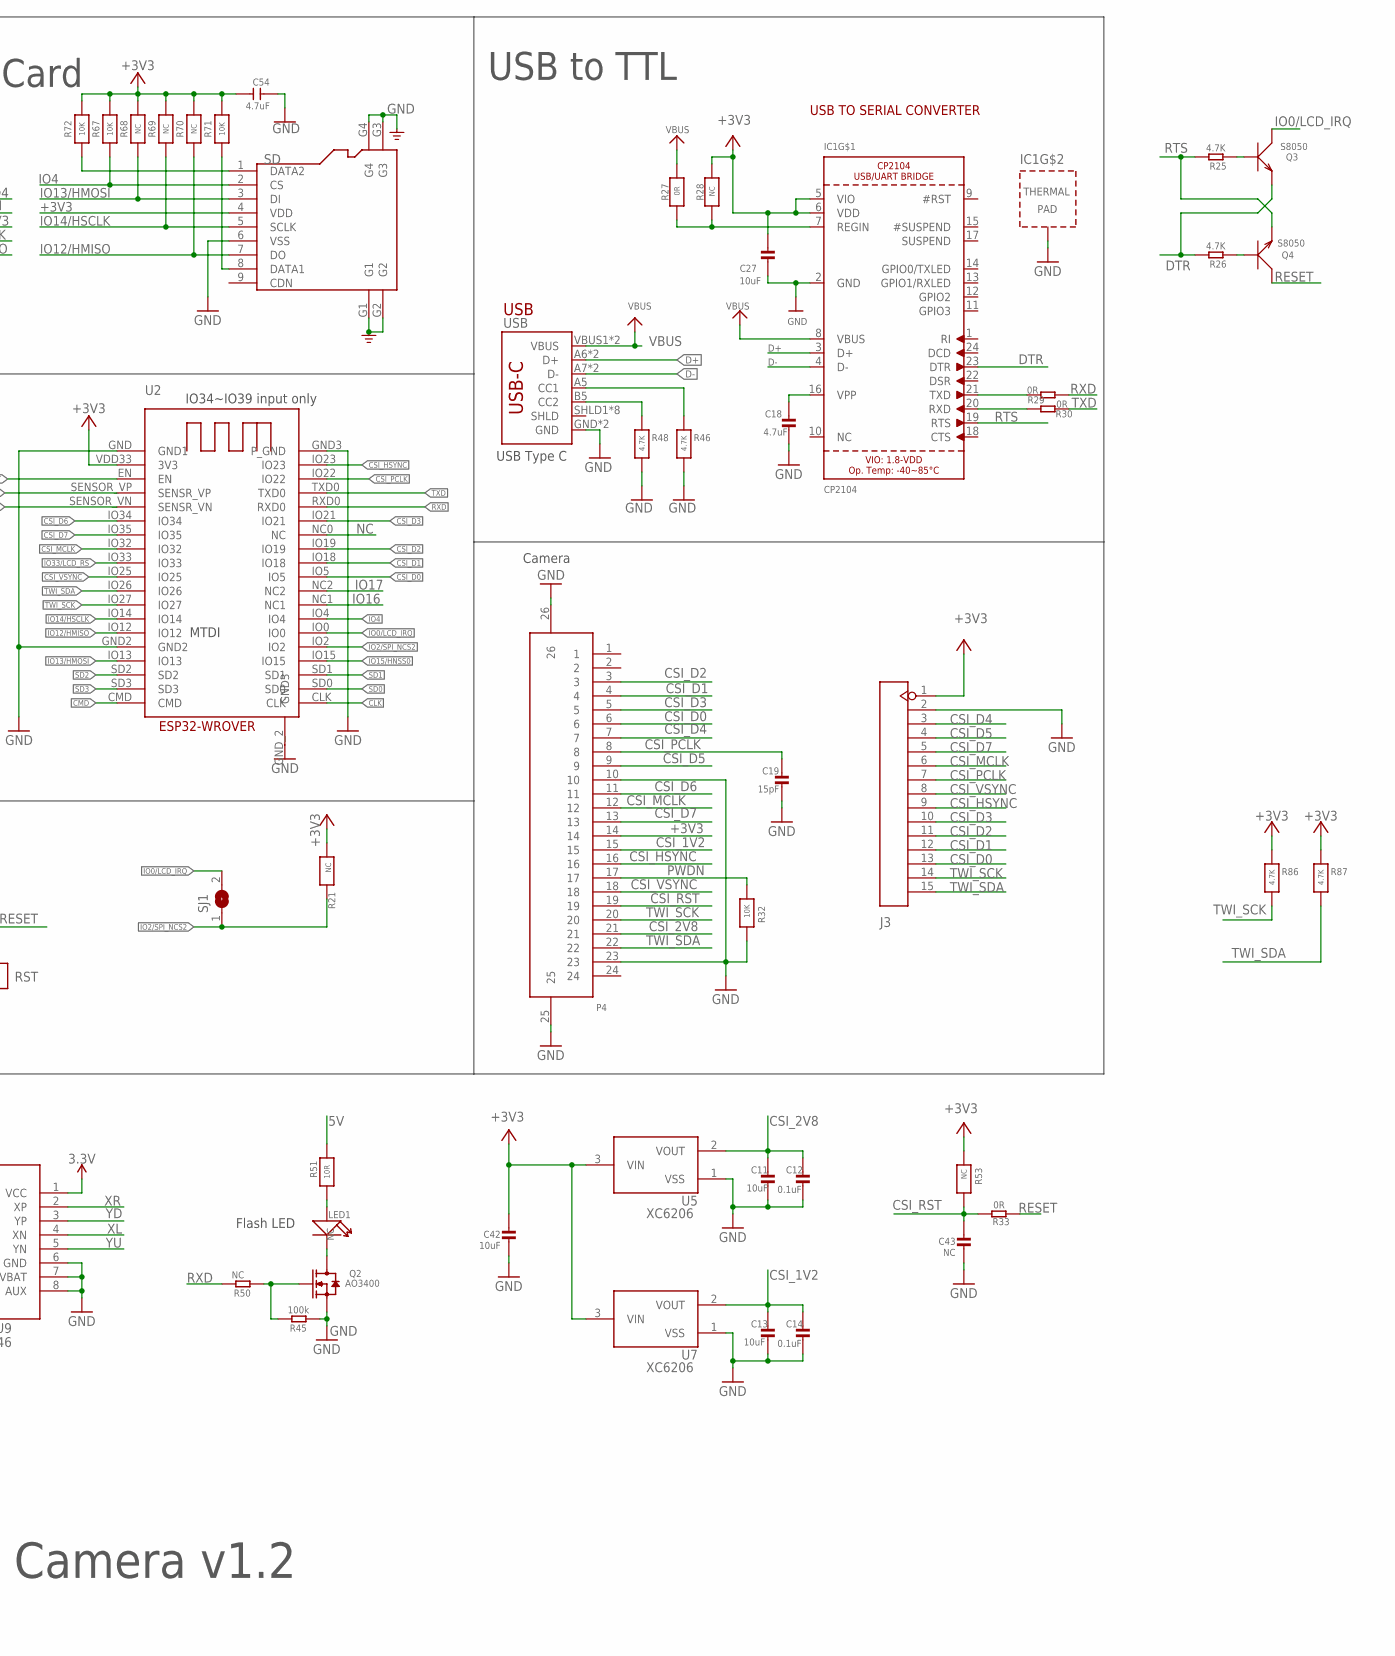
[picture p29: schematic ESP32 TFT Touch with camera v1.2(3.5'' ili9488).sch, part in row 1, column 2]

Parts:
C11, C13, C25, C26, C27, C42: 10uF; 0603-NO
C12, C14: 0.1uF; 0603-NO
C15: 100nF; 0603-NO
C16: 4.7uF/16V; 0603
C17: 10uF; C0603
C18: 4.7uF; 0603-NO
C19: 15pF; 0603-NO
C20, C23, C29, C31, C33: 10uF; DISCRETE_C0603
C21, C24, C30, C32, C34: 0.1uF; DISCRETE_C0603
C22: 10uF; 0603
C28: 100nf; 0603-NO
C43: NC; 0603-NO
C54: 4.7uF; DISCRETE_C0603
D3: YELLOW; CHIPLED_0805_NOOUTLINE
D4: SMF05C; SOT363
D5: SS34; DO-214AC
D6: 1N4148WS; SOD323
FLASH: BUTTON; 157SW
IC1: CP2104; QFN24_4MM_SMSC
J3: HEADER-1X15P; SMD15-2.54P8.5H
LED1: NC; DISCRETE_LED-3528
P2, P3: AFC01-S06FCC-00; SMD8-50P-740L535W
P4: FPC-24P; SMD26-50P-1760L450W
P5: FPC-40P; SMD42-50P-2560L490W
Q2: AO3400; SOT23@1
Q3, Q4: S8050; SOT23
Q5: S8050; SPARKFUN_SOT23
R1, R24, R29, R30, R33: 0R; R0603
R2, R31, R50: NC; R0603
R16: 470R; 0603-NO
R21, R28, R53, R68, R69, R70: NC; 0603-NO
R22, R23: 10K; R0603
R25, R26: 4.7K; R0603
R27: 0R; 0603-NO
R32, R67, R71, R72: 10K; 0603-NO
R34, R40: 10K; DISCRETE_R0603
R35, R42, R43, R44, R47, R52, R54: NC; DISCRETE_R0603
R36, R49: 0R; DISCRETE_R0603
R37, R38, R39, R41: 10R; DISCRETE_R0603
R45: 100k; R0603
R46, R48, R86, R87: 4.7K; 0603-NO
R51: 10R; 0603-NO
RST: BUTTON; 157SW
SD: HOLDER-MICROSD-9P; 9P-SMD-W/-RING
SJ1: SJ
U2: ESP32-WROVER
U4: LD1117/3.3v; SOT89
U5, U7: XC6206; SOT-23
U6: ESP-WROOM-32
U8: NS2009; MSOP10
U9: XPT2046; TSSOP16-65P-560L910W
USB: USB_C5; USB-C-16P-5

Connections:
3.3V: C20.2, C21.2, C23.2, C24.2, C29.2, C30.2, C31.1, C32.1, C33.2, C34.2, P2.1, P3.1, P5.6, P5.7, P5.12, P5.33, P5.38, P5.40, R1.2, R36.2, R40.2, R42.2, R43.2, R44.2, R47.2, R52.2, R54.2, U8.1 (VDD), U9.1 (VCC), U9.9 (VREF), U9.10 (IOVDD)
5V: C16.1, D5.C, R51.1, U4.3 (IN)
+3V3: C17.1, C22.1, C26.1, C27.1, C42.1, C54.2, D3.A, D4.4 (C3), IC1.5 (VIO), IC1.6 (VDD), J3.1, P4.14, R1.1, R21.1, R22.2, R23.2, R28.1, R53.1, R67.2, R68.2, R69.2, R70.2, R71.2, R72.2, R86.1, R87.1, SD.4 (VDD), U2.VDD33 (3V3), U4.2 (OUT), U4.4 (OUT), U5.3 (VIN), U6.2 (3V3), U7.3 (VIN)
CLK: U2.CLK, U6.20 (CLK)
CMD: U2.CMD, U6.19 (CMD)
CSI_1V2: C13.1, C14.1, P4.15, U7.2 (VOUT)
CSI_2V8: C11.1, C12.1, P4.21, U5.2 (VOUT)
CSI_D0: J3.13, P4.6, U2.IO5, U6.29 (IO5)
CSI_D1: J3.12, P4.4, U2.IO18, U6.30 (IO18)
CSI_D2: J3.11, P4.3, U2.IO19, U6.31 (IO19)
CSI_D3: J3.10, P4.5, U2.IO21, U6.33 (IO21)
CSI_D4: J3.3, P4.7, U2.SENSOR_VP (SENSR_VP), U6.4 (SENSOR_VP)
CSI_D5: J3.4, P4.9, U2.SENSOR_VN (SENSR_VN), U6.5 (SENSOR_VN)
CSI_D6: P4.11, U2.IO34, U6.6 (IO34)
CSI_D7: J3.5, P4.13, U2.IO35, U6.7 (IO35)
CSI_HSYNC: J3.9, P4.16, U2.IO23, U6.37 (IO23)
CSI_MCLK: J3.6, P4.12, U2.IO32, U6.8 (IO32)
CSI_PCLK: C19.1, J3.7, P4.8, U2.IO22, U6.36 (IO22)
CSI_RST: C43.1, P4.19, R33.2, R53.2
CSI_VSYNC: J3.8, P4.18, U2.IO25, U6.10 (IO25)
D+: IC1.3 (D+), USB.A6 (D+), USB.B6 (D+)
D-: IC1.4 (D-), USB.A7 (D-), USB.B7 (D-)
DTR: IC1.23 (DTR), Q3.2 (E), R26.2
GND: C11.2, C12.2, C13.2, C14.2, C15.2, C16.2, C17.2, C18.2, C19.2, C20.1, C21.1, C22.2, C23.1, C24.1, C25.2, C26.2, C27.2, C28.2, C29.1, C30.1, C31.2, C32.2, C33.1, C34.1, C42.2, C43.2, C54.1, D4.2 (A), FLASH.1, IC1.2 (GND), IC1.THERM (TP), J3.2, P2.6, P2.7, P2.8, P3.2, P3.7, P3.8, P4.10, P4.23, P4.25, P4.26, P5.5, P5.16, P5.17, P5.18, P5.19, P5.20, P5.21, P5.22, P5.23, P5.24, P5.25, P5.26, P5.27, P5.28, P5.29, P5.30, P5.31, P5.32, P5.37, P5.41, P5.42, Q2.2 (S), Q5.2 (E), R16.1, R32.2, R34.1, R35.1, R45.1, R46.2, R48.2, R49.1, RST.1, SD.6 (VSS), SD.G1, SD.G2, SD.G3, SD.G4, U2.GND (GND1), U2.GND2, U2.GND3 (P_GND), U2.GND_2 (GND3), U4.1 (GND), U5.1 (VSS), U6.1 (GND), U6.15 (GND), U6.38 (GND), U7.1 (VSS), U8.6 (GND), U9.6 (GND), U9.7 (VBAT), U9.8 (AUX), USB.GND, USB.GND2 (GND)
IM1: P5.39, R35.2, R36.1
IO0/LCD_IRQ: P2.4, P3.5, Q3.3 (C), R22.1, R24.2, R42.1, SJ1.2, U2.IO0, U6.25 (IO0), U8.7 (PENIRQ), U9.11 (PENIRQ)
IO2/SPI_NCS2: R21.2, R54.1, SJ1.1, U2.IO2, U6.24 (IO2), U9.15 (CS)
IO4: D4.1 (C1), R67.1, SD.2 (CS), U2.IO4, U6.26 (IO4)
IO12/HMISO: D4.6 (C5), D6.-, R2.1, R70.1, SD.7 (DO), U2.IO12, U6.14 (IO12), U9.12 (DOUT)
IO13/HMOSI: D4.3 (C2), P5.13, R68.1, SD.3 (DI), U2.IO13, U6.16 (IO13), U9.14 (DIN)
IO14/HSCLK: D4.5 (C4), P5.11, R69.1, SD.5 (SCLK), U2.IO14, U6.13 (IO14), U9.16 (DCLK)
IO15/HNSS0: P5.9, U2.IO15, U6.23 (IO15)
IO16: U2.NC1, U6.27 (IO16)
IO17: U2.NC2, U6.28 (IO17)
IO33/LCD_RS: P5.10, R34.2, U2.IO33, U6.9 (IO33)
LCD_BCK: R31.2, R41.2
LCD_BUSY: U9.13 (BUSY)
unnamed: C18.1, IC1.16 (VPP)
unnamed: Q4.1 (B), R26.1
unnamed: Q3.1 (B), R25.1
unnamed: D6.+, P5.14, R2.2
unnamed: Q2.1 (G), R45.2, R50.1
unnamed: FLASH.2, R24.1
unnamed: D3.C, R16.2
unnamed: LED1.1 (+), R51.2
unnamed: LED1.2 (-), Q2.3 (D)
unnamed: R46.1, USB.A5 (CC1)
unnamed: R48.1, USB.B5 (CC2)
unnamed: IC1.7 (REGIN), R27.2, R28.2
unnamed: IC1.21 (TXD), R29.2
unnamed: IC1.20 (RXD), R30.2
unnamed: P5.34, R37.1
unnamed: P5.35, R38.1
unnamed: P5.36, R39.1
unnamed: Q5.1 (B), R40.1, R41.1
unnamed: Q5.3 (C), R37.2, R38.2, R39.2
unnamed: R49.2, R52.1, U8.8 (A0)
unnamed: R72.1, SD.1 (DATA2)
unnamed: R71.1, SD.8 (DATA1)
NC: U2.NC0 (NC), U6.32 (NC)
PWDN: P4.17, R32.1
RESET: C28.1, P2.5, P3.6, P5.15, Q4.3 (C), R23.1, R33.1, R47.1, RST.2, U2.EN, U6.3 (EN)
RTS: IC1.19 (RTS), Q4.2 (E), R25.2
RXD: R29.1, R50.2, U2.RXD0, U6.34 (RXD0)
SD0: U2.SD0, U6.21 (SDO)
SD1: U2.SD1, U6.22 (SD1)
SD2: U2.SD2, U6.17 (SD2)
SD3: U2.SD3, U6.18 (SD3)
TWI_SCK: J3.14, P2.3, P3.3, P4.20, R43.1, R86.2, U2.IO27, U6.12 (IO27), U8.10 (SCL)
TWI_SDA: J3.15, P2.2, P3.4, P4.22, R44.1, R87.2, U2.IO26, U6.11 (IO26), U8.9 (SDA)
TXD: R30.1, R31.1, U2.TXD0, U6.35 (TXD0)
VBUS: C15.1, C25.1, D5.A, IC1.8 (VBUS), R27.1, USB.VBUS1 (VBUS), USB.VBUS2 (VBUS)
XL: P5.1, U8.4 (XN), U9.4 (XN)
XR: P5.3, U8.2 (XP), U9.2 (XP)
YD: P5.4, U8.3 (YP), U9.3 (YP)
YU: P5.2, U8.5 (YN), U9.5 (YN)

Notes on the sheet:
www.makerfabs.com
Design by Charlin
USB
LEDS
POWER AND FILTERING
USB TO SERIAL CONVERTER
key flash
ESP32 TFT Touch with Camera v1.2
MTDI
IO34~IO39 input only
POWER
USB to TTL
USB Type C
SD Card
Flash LED
Camera
NS2009
FT6236
Closer to IC
Back Light

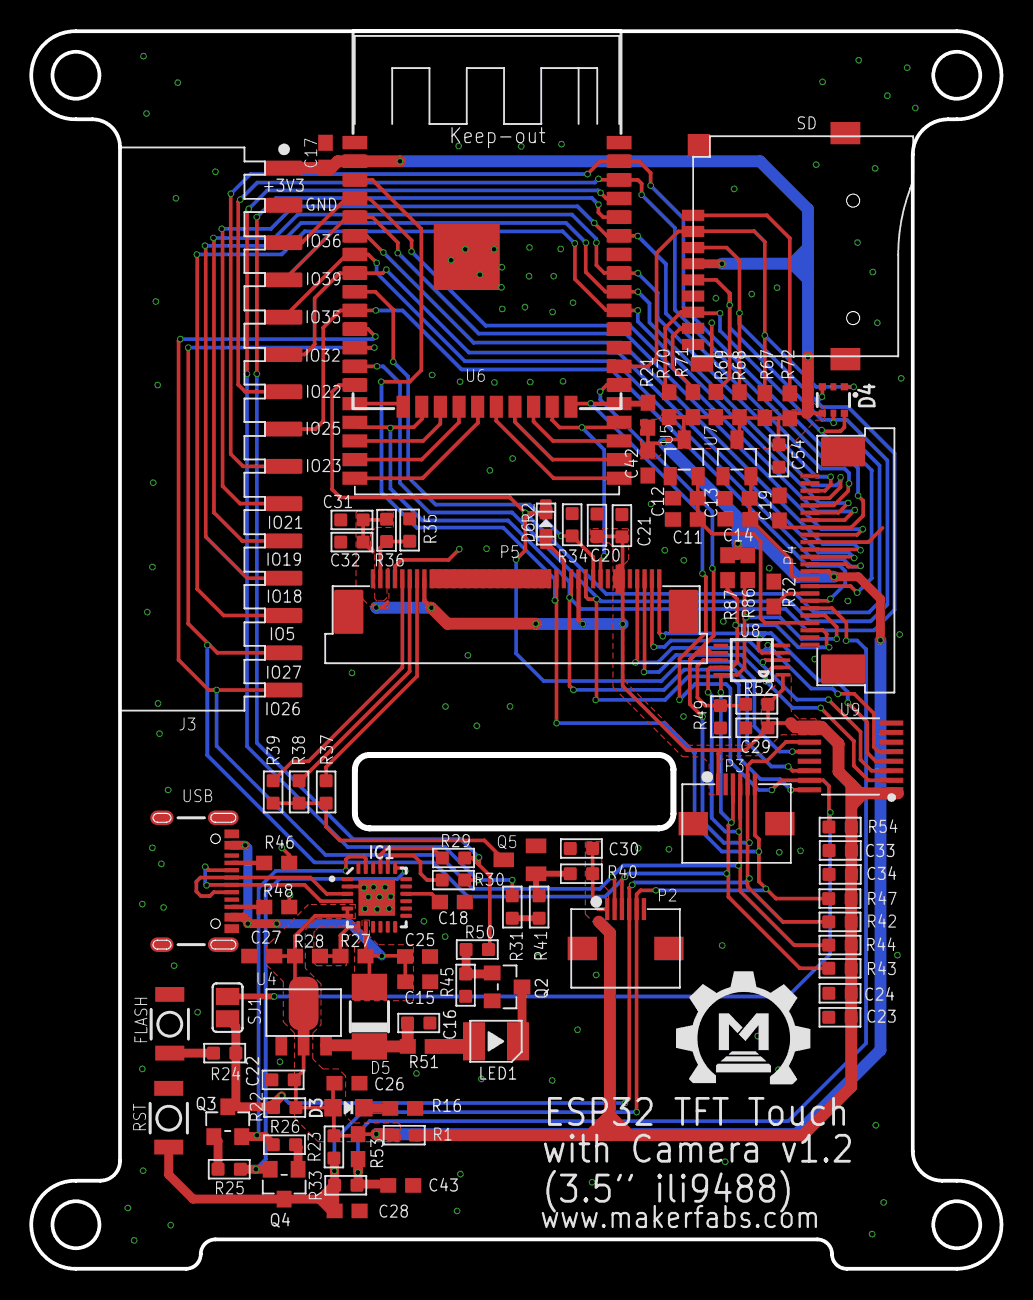
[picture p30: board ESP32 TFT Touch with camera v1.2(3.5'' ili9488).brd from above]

Board: 2 copper layers, 66.1 x 84.3 mm, 100 parts (0 on the bottom side), 75 nets.

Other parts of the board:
U$1: MAKERFABS_0.3

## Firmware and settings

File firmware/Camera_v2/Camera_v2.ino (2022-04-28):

#include <SPI.h>
#include <SD.h>
#include <FS.h>
#include <esp_camera.h>
#include <HTTPClient.h>
#include <LovyanGFX.hpp>

#include "makerfabs_pin.h"
#define CAMERA_MODEL_MAKERFABS
#include "camera_pins.h"
//#define WIFI_MODE

#define ARRAY_LENGTH 320 * 240 * 3
#define SCRENN_ROTATION 3

/*
!!!MAKE SURE CHOICE RIGHT TOUCH SCREEN DRIVER!!!

You can only use one type:Resistive or Capacitive.

!!!MAKE SURE CHOICE RIGHT TOUCH SCREEN DRIVER!!!
*/
// #define NS2009_TOUCH  //Resistive screen driver
#define FT6236_TOUCH // Capacitive screen driver

#ifdef NS2009_TOUCH
#include "NS2009.h"
const int i2c_touch_addr = NS2009_ADDR;
#define get_pos ns2009_pos
#endif

#ifdef FT6236_TOUCH
#include "FT6236.h"
const int i2c_touch_addr = TOUCH_I2C_ADD;
#define get_pos ft6236_pos
#endif

// SPI control
#define SPI_ON_TFT digitalWrite(ESP32_TSC_9488_LCD_CS, LOW)
#define SPI_OFF_TFT digitalWrite(ESP32_TSC_9488_LCD_CS, HIGH)
#define SPI_ON_SD digitalWrite(ESP32_TSC_9488_SD_CS, LOW)
#define SPI_OFF_SD digitalWrite(ESP32_TSC_9488_SD_CS, HIGH)

struct LGFX_Config
{
    static constexpr spi_host_device_t spi_host = ESP32_TSC_9488_LCD_SPI_HOST;
    static constexpr int dma_channel = 1;
    static constexpr int spi_sclk = ESP32_TSC_9488_LCD_SCK;
    static constexpr int spi_mosi = ESP32_TSC_9488_LCD_MOSI;
    static constexpr int spi_miso = ESP32_TSC_9488_LCD_MISO;
};

static lgfx::LGFX_SPI<LGFX_Config> tft;
static LGFX_Sprite sprite(&tft);
static lgfx::Panel_ILI9488 panel;

const uint8_t img_rgb888_320_240_head[54] = {
    0x42, 0x4d, 0x36, 0x84, 0x3, 0x0, 0x0, 0x0, 0x0, 0x0, 0x36, 0x0, 0x0, 0x0, 0x28, 0x0,
    0x0, 0x0, 0x40, 0x1, 0x0, 0x0, 0xf0, 0x0, 0x0, 0x0, 0x1, 0x0, 0x18, 0x0, 0x0, 0x0,
    0x0, 0x0, 0x0, 0x84, 0x3, 0x0, 0x0, 0x0, 0x0, 0x0, 0x0, 0x0, 0x0, 0x0, 0x0, 0x0,
    0x0, 0x0, 0x0, 0x0, 0x0, 0x0};

String imgname = "";
int img_index = 0;
int pos[2] = {0, 0};
int stream_flag = 1;

void setup()
{
    esp32_init();
    camera_init();
}

void loop()
{
    camera_fb_t *fb = NULL;
    fb = esp_camera_fb_get();

    if (stream_flag == 1)
    {
        tft.pushImage(0, 0, fb->width, fb->height, (lgfx::swap565_t *)fb->buf);
    }

    get_pos(pos);
    pos_rotation(pos, SCRENN_ROTATION);

    if (320 < pos[0] && pos[0] < 480)
    {
        if (0 < pos[1] && pos[1] < 80)
        {
            if (stream_flag == 1)
            {
                void *ptrVal = NULL;
                ptrVal = heap_caps_malloc(ARRAY_LENGTH, MALLOC_CAP_SPIRAM);
                uint8_t *rgb = (uint8_t *)ptrVal;
                fmt2rgb888(fb->buf, fb->len, PIXFORMAT_RGB565, rgb);
                if (save_image(SD, rgb) == -1)
                {
                    show_log(5);
                }
                else
                    show_log(0);
                heap_caps_free(ptrVal);
                rgb = NULL;
            }
            else
            {
                show_log(3);
            }
        }

        if (pos[1] > 80 && pos[1] < 160)
        {
            show_log(1);
            stream_flag = 0;
            tft.fillRect(0, 0, 320, 240, TFT_BLACK);
            print_img(SD, imgname, 320, 240);

#ifdef WIFI_MODE
            TestPostFileStream(imgname);
            show_log(4);
#endif
        }

        if (pos[1] < 240 && pos[1] > 160)
        {
            stream_flag = 1;
            show_log(2);
        }
    }
    esp_camera_fb_return(fb);
}

// ILI9488 init and SD card init
void esp32_init()
{
    int SD_init_flag = 0;
    Serial.begin(115200);
    Serial.println("ILI9488 Test!");

    // I2C init
    Wire.begin(ESP32_TSC_9488_I2C_SDA, ESP32_TSC_9488_I2C_SCL);
    byte error, address;

    Wire.beginTransmission(i2c_touch_addr);
    error = Wire.endTransmission();

    if (error == 0)
    {
        Serial.print("I2C device found at address 0x");
        Serial.print(i2c_touch_addr, HEX);
        Serial.println("  !");
    }
    else if (error == 4)
    {
        Serial.print("Unknown error at address 0x");
        Serial.println(i2c_touch_addr, HEX);
    }

    // SPI init
    pinMode(ESP32_TSC_9488_SD_CS, OUTPUT);
    pinMode(ESP32_TSC_9488_LCD_CS, OUTPUT);
    SPI_OFF_SD;
    SPI_OFF_TFT;

    SPI.begin(ESP32_TSC_9488_HSPI_SCK, ESP32_TSC_9488_HSPI_MISO, ESP32_TSC_9488_HSPI_MOSI);

    // SD(SPI) init
    SPI_ON_SD;
    if (!SD.begin(ESP32_TSC_9488_SD_CS, SPI, 40000000))
    {
        Serial.println("Card Mount Failed");
        SD_init_flag = 1;
    }
    else
    {
        Serial.println("Card Mount Successed");
    }
    SPI_OFF_SD;

    Serial.println("SD init over.");

    // TFT(SPI) init
    SPI_ON_TFT;
    set_tft();
    tft.begin();
    tft.setRotation(SCRENN_ROTATION);
    tft.fillScreen(TFT_RED);
    delay(1500);
    tft.fillScreen(TFT_GREEN);
    delay(1500);
    tft.fillScreen(TFT_WHITE);
    delay(1500);
    tft.fillScreen(TFT_BLUE);
    delay(1500);
    tft.fillScreen(TFT_BLACK);
    delay(1500);

    // if SD init failed
    if (SD_init_flag == 1)
    {
        tft.setTextColor(TFT_RED);
        tft.setTextSize(3);
        tft.setCursor(10, 10);
        tft.println("  SD card initialization failed, please re-insert.");
        tft.setCursor(10, 60);
        tft.println("  Or touch the screen using only the camera (showing only the output stream)");

        tft.fillRect(100, 160, 280, 160, TFT_BLUE);
        tft.setCursor(130, 190);
        tft.println("    TOUCH");
        tft.setCursor(140, 220);
        tft.println("     TO");
        tft.setCursor(120, 250);
        tft.println("   CONTINUE");

        int pos[2] = {0, 0};

        while (1)
        {
            get_pos(pos);

            if (pos[0] > 100 && pos[0] < 380 && pos[1] > 160 && pos[1] < 320)
                break;
            delay(100);
        }
    }
    else
    {
        tft.setRotation(1);

        SPI_OFF_TFT;
        delay(10);
        print_img(SD, "/logo.bmp", 480, 320);
        SPI_ON_TFT;

        delay(1000);
        tft.setRotation(3);
    }

    draw_button();
    SPI_OFF_TFT;
    Serial.println("TFT init over.");

#ifdef WIFI_MODE
    // Trying to solve pn open, type:2 0 error with this line:
    WiFi.mode(WIFI_OFF);

    for (uint8_t t = 4; t > 0; t--)
    {
        Serial.printf("[SETUP] WAIT %d...\n", t);
        Serial.flush();
        delay(200);
    }

    Serial.println("Connecting to WIFI");
    // wait for WiFi connection
    WiFi.mode(WIFI_STA);
    WiFi.begin("Makerfabs", "20160704");
    while (WiFi.status() != WL_CONNECTED)
    {
        Serial.print(".");
        delay(50);
    }
    Serial.println("\nWIFI CONNECTED");
#endif
}

// Camera setting
void camera_init()
{
    // camera config
    camera_config_t config;
    config.ledc_channel = LEDC_CHANNEL_0;
    config.ledc_timer = LEDC_TIMER_0;
    config.pin_d0 = Y2_GPIO_NUM;
    config.pin_d1 = Y3_GPIO_NUM;
    config.pin_d2 = Y4_GPIO_NUM;
    config.pin_d3 = Y5_GPIO_NUM;
    config.pin_d4 = Y6_GPIO_NUM;
    config.pin_d5 = Y7_GPIO_NUM;
    config.pin_d6 = Y8_GPIO_NUM;
    config.pin_d7 = Y9_GPIO_NUM;
    config.pin_xclk = XCLK_GPIO_NUM;
    config.pin_pclk = PCLK_GPIO_NUM;
    config.pin_vsync = VSYNC_GPIO_NUM;
    config.pin_href = HREF_GPIO_NUM;
    config.pin_sscb_sda = SIOD_GPIO_NUM;
    config.pin_sscb_scl = SIOC_GPIO_NUM;
    config.pin_pwdn = PWDN_GPIO_NUM;
    config.pin_reset = RESET_GPIO_NUM;
    config.xclk_freq_hz = 20000000;

    config.pixel_format = PIXFORMAT_RGB565;
    config.frame_size = FRAMESIZE_QVGA;
    config.jpeg_quality = 10;
    config.fb_count = 1;

    // camera init
    esp_err_t err = esp_camera_init(&config);
    if (err != ESP_OK)
    {
        Serial.printf("Camera init failed with error 0x%x", err);
        while (1)
            ;
    }

    sensor_t *s = esp_camera_sensor_get();
    // initial sensors are flipped vertically and colors are a bit saturated
    if (s->id.PID == OV2640_PID)
    {
        s->set_vflip(s, 0);   // vertical flip
        s->set_hmirror(s, 0); // Horizontal mirror

        s->set_brightness(s, 0); // up the blightness just a bit
        s->set_saturation(s, 1); // lower the saturation
    }
    // drop down frame size for higher initial frame rate
    s->set_framesize(s, FRAMESIZE_QVGA);

    show_log(2);
}

// Save image to SD card
int save_image(fs::FS &fs, uint8_t *rgb)
{
    SPI_ON_SD;
    imgname = "/" + String(img_index) + "write.bmp";
    img_index++;

    Serial.println("Image name：" + imgname);

    File f = fs.open(imgname, "w");
    if (!f)
    {
        Serial.println("Failed to open file for writing");
        return -1;
    }

    f.write(img_rgb888_320_240_head, 54);
    f.write(rgb, 230400);

    f.close();
    SPI_OFF_SD;
    return 0;
}

void draw_button()
{
    SPI_ON_TFT;
    tft.fillScreen(TFT_BLACK);
    tft.fillRect(330, 0, 150, 70, TFT_BLUE);
    tft.fillRect(330, 80, 150, 70, TFT_BLUE);
    tft.fillRect(330, 160, 150, 70, TFT_BLUE);

    tft.setTextColor(TFT_WHITE);
    tft.setTextSize(1);
    tft.setCursor(340, 30);
    tft.println("TAKE PHOTO");
    tft.setCursor(340, 110);
    tft.println("LAST PHOTO");
    tft.setCursor(340, 190);
    tft.println("START STREAM");

    SPI_OFF_TFT;
}

// Display image from file
int print_img(fs::FS &fs, String filename, int x, int y)
{
    SPI_ON_SD;
    File f = fs.open(filename, "r");
    if (!f)
    {
        Serial.println("Failed to open file for reading");
        f.close();
        return 0;
    }

    f.seek(54);
    int X = x;
    int Y = y;
    uint8_t RGB[3 * X];
    for (int row = 0; row < Y; row++)
    {
        f.seek(54 + 3 * X * row);
        f.read(RGB, 3 * X);
        SPI_OFF_SD;
        tft.pushImage(0, row, X, 1, (lgfx::rgb888_t *)RGB);
        SPI_ON_SD;
    }

    f.close();
    SPI_OFF_SD;
    return 0;
}

void show_log(int cmd_type)
{
    SPI_ON_TFT;
    tft.fillRect(0, 240, 480, 80, TFT_BLACK);

    tft.setTextColor(TFT_RED);
    tft.setTextSize(2);
    tft.setCursor(30, 280);

    switch (cmd_type)
    {
    case 0:
        tft.println("TAKE PHOTO");
        tft.println(imgname);
        break;

    case 1:
        tft.println("Show last photo");
        tft.println(imgname);
        break;

    case 2:
        tft.println("STREAMING");
        break;

    case 3:
        tft.println("NEED STREAM");
        break;

    case 4:
        tft.println("Show last photo");
        tft.println(imgname);
        tft.println("Upload success");
        break;
    case 5:
        tft.println("Write sd card wrong");
        break;

    default:
        break;
    }
    SPI_OFF_TFT;
}

#ifdef WIFI_MODE
void TestPostFileStream(String file_name)
{
    SPI_ON_SD;
    HTTPClient http;
    String filename = String(img_index - 1) + "write.bmp";
    String pathname = file_name;
    String archDomainAddress = "http://192.168.1.128:5002/json";

    http.begin(archDomainAddress);
    http.addHeader("Content-Type", "text/plain");

    File payloadFile = SD.open(pathname, FILE_READ);
    if (payloadFile)
    {
        Serial.println("File exists, starting POST");

        http.addHeader("File-Name", filename);
        int httpCode = http.sendRequest("POST", &payloadFile, payloadFile.size());

        if (httpCode > 0)
        {
            // HTTP header has been send and Server response header has been handled
            Serial.printf("[HTTP] POST... code: %d\n", httpCode);

            // file found at server
            if (httpCode >= 200 && httpCode < 300)
            {
                String payload = http.getString();
                Serial.println("SUCCESS! DATA RECEIVED: ");
                Serial.println(payload);
            }
        }
        else
        {
            Serial.printf("[HTTP] POST... failed, error: %s\n", http.errorToString(httpCode).c_str());
        }
    }
    else
    {
        Serial.println("File does not exist!");
    }
    payloadFile.close();
    http.end();
    SPI_OFF_SD;
    Serial.println("POST over");
}
#endif

void set_tft()
{
    panel.freq_write = 40000000;
    panel.freq_fill = 40000000;
    panel.freq_read = 16000000;

    panel.spi_cs = ESP32_TSC_9488_LCD_CS;
    panel.spi_dc = ESP32_TSC_9488_LCD_DC;
    panel.gpio_rst = ESP32_TSC_9488_LCD_RST;
    panel.gpio_bl = ESP32_TSC_9488_LCD_BL;

    tft.setPanel(&panel);
}

// transform touch screen pos
void pos_rotation(int pos[2], int rotation)
{
    if (pos[0] == -1)
        return;
    if (rotation == 0)
    {
        return;
    }
    if (rotation == 3)
    {
        int tempx = 480 - pos[1];
        int tempy = pos[0];
        pos[0] = tempx;
        pos[1] = tempy;
    }
}

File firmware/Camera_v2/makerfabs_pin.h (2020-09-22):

/*
-------------------------------------------------
titile  :   Makerfabs IO define
author  :   Vincent
create  :   2020/9/4
version :   1.1
update  :   2020/9/11

Note:
    v1.0 : Create Project.
    v1.1 : Add MakePython Audio support.

1.
For easy use ESP32 GPIO,define SPI, I2C, and LCD, SDcard pins.
And define some parameters, such as screen size.

2.
Sigillum:
MP = MakePython
MP_ESP32 = MakePython ESP32 SSD1306
MP_ESP32_COLOR = MakePython ESP32 Color LCD (ST7789)

TSC = Touch Screen Camera
ESP32_TSC_9488 = ESP32 Touch Screen Camera With ILI9488

3.
//#define ESP32_COLOR_7789 OK
"Ok" means tested and ready to use
Don't use "ERR" or "TEST"

4.
For the motherboard combination expansion board.
This is to be determined and may be modified.
A more prudent approach is to copy the pin value directly.

-------------------------------------------------
Support List:

    (1)MakePython:
        MakePython ESP32 COLOR LCD
        MakePython ESP32 SSD1306
        MakePython Audio

    (2)Touch Screen Camera:
        ESP32 Touch Screen Camera With 9488

-------------------------------------------------
*/

//BOARD

//#define MP_ESP32 OK
//#define MP_ESP32_COLOR OK
#define ESP32_TSC_9488 OK
//#define ESP32_ILI9341 ERR don't use

//SHIELD
//#define MP_AUDIO OK
//#define MP_A9G OK

//******************************************************************************

/*
update  :   2020/9/8
name    :   MakePython ESP32 SSD1306
sigillum:   MP_ESP32_COLOR
wiki    :   https://www.makerfabs.com/wiki/index.php?title=MakePython_ESP32
module  :   
            (1) 1.3inch OLED SSD1306

*/
#ifdef MP_ESP32

#define MP_ESP32_FLASH_BUTTON 0

//I2C
#define MP_ESP32_I2C_SDA 4
#define MP_ESP32_I2C_SCL 5

//HSPI
#define MP_ESP32_HSPI_MOSI 13
#define MP_ESP32_HSPI_MISO 12
#define MP_ESP32_HSPI_SCK 14
#define MP_ESP32_HSPI_CS 15

//VSPI
#define MP_ESP32_VSPI_MOSI 23
#define MP_ESP32_VSPI_MISO 19
#define MP_ESP32_VSPI_SCK 18
#define MP_ESP32_VSPI_CS 5

//SSD1306
#define MP_ESP32_SSD1306_I2C_ADDR 0x3C
#define MP_ESP32_SSD1306_WIDTH 128 // OLED display width, in pixels
#define MP_ESP32_SSD1306_HEIGHT 64 // OLED display height, in pixels
#define MP_ESP32_SSD1306_RST -1

#endif

/*
update  :   2020/9/11
name    :   MakePython ESP32 COLOR LCD
sigillum:   MP_ESP32_COLOR
wiki    :   https://www.makerfabs.com/wiki/index.php?title=MakePython_ESP32_Color_LCD
module  :   
            (1) 1.3inch TFT ST7789 driver

*/
#ifdef MP_ESP32_COLOR

//I2C
#define MP_ESP32_COLOR_I2C_SDA 4
#define MP_ESP32_COLOR_I2C_SCL 5

//HSPI
#define MP_ESP32_COLOR_HSPI_MOSI 13
#define MP_ESP32_COLOR_HSPI_MISO 12
#define MP_ESP32_COLOR_HSPI_SCK 14
#define MP_ESP32_COLOR_HSPI_CS 15

//VSPI
#define MP_ESP32_COLOR_VSPI_MOSI 23
#define MP_ESP32_COLOR_VSPI_MISO 19
#define MP_ESP32_COLOR_VSPI_SCK 18
#define MP_ESP32_COLOR_VSPI_CS 5

//ST7789
#define MP_ESP32_COLOR_LCD_MOSI MP_ESP32_COLOR_HSPI_MOSI
#define MP_ESP32_COLOR_LCD_MISO MP_ESP32_COLOR_HSPI_MISO
#define MP_ESP32_COLOR_LCD_SCK MP_ESP32_COLOR_HSPI_SCK

#define MP_ESP32_COLOR_LCD_CS 15

#define MP_ESP32_COLOR_LCD_RST 21
#define MP_ESP32_COLOR_LCD_DC 22
#define MP_ESP32_COLOR_LCD_BL -1 //5

#define MP_ESP32_COLOR_LCD_WIDTH 240
#define MP_ESP32_COLOR_LCD_HEIGHT 240
#define MP_ESP32_COLOR_LCD_SPI_HOST HSPI_HOST

#endif

/*
update  :   2020/9/22
name    :   ESP32 Touch Screen Camera With ILI9488
sigillum:   ESP32_TSC_9488 
wiki    :   
module  :   
            (1) 3.5inch TFT ILI9488 driver
            (2) SDcard Reader
            (3) I2C Touch Screen(NS2009 or Ft6236)
            (4) OV2640 Camera
note    :
            (1) In camera need VSPI, but actually use HSPI. Why?
*/

#ifdef ESP32_TSC_9488

//I2C
#define ESP32_TSC_9488_I2C_SDA 26
#define ESP32_TSC_9488_I2C_SCL 27

//SPI
#define ESP32_TSC_9488_HSPI_MOSI 13
#define ESP32_TSC_9488_HSPI_MISO 12
#define ESP32_TSC_9488_HSPI_SCK 14
#define ESP32_TSC_9488_HSPI_CS 15

//ILI9488
#define ESP32_TSC_9488_LCD_MOSI ESP32_TSC_9488_HSPI_MOSI
#define ESP32_TSC_9488_LCD_MISO ESP32_TSC_9488_HSPI_MISO
#define ESP32_TSC_9488_LCD_SCK ESP32_TSC_9488_HSPI_SCK

#define ESP32_TSC_9488_LCD_CS 15

#define ESP32_TSC_9488_LCD_RST 26
#define ESP32_TSC_9488_LCD_DC 33
#define ESP32_TSC_9488_LCD_BL -1

#define ESP32_TSC_9488_LCD_WIDTH 320
#define ESP32_TSC_9488_LCD_HEIGHT 480
#define ESP32_TSC_9488_LCD_SPI_HOST VSPI_HOST   //?? IF use HSPI, will wrong.

//SDcard
#define ESP32_TSC_9488_SD_MOSI ESP32_TSC_9488_HSPI_MOSI
#define ESP32_TSC_9488_SD_MISO ESP32_TSC_9488_HSPI_MISO
#define ESP32_TSC_9488_SD_SCK ESP32_TSC_9488_HSPI_SCK

#define ESP32_TSC_9488_SD_CS 4

#endif

/*
    name    :   ESP32 Touch Screen Camera With ILI9341
    Not ready
*/

#ifdef ESP32_ILI9341

#define LCD_MOSI 13
#define LCD_MISO 12
#define LCD_SCK 14
#define LCD_CS 18
#define LCD_RST 21
#define LCD_DC 22
#define LCD_BL 19 //5

#define LCD_WIDTH 240
#define LCD_HEIGHT 240
#define LCD_SPI_HOST VSPI_HOST

#endif
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

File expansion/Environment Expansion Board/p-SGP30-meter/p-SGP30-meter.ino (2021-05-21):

/*
 An example showing 'ring' analogue meter on a TFT
 colour screen

 Needs Fonts 2, 4 and 7 (also Font 6 if using a large size meter)
 */

// Meter colour schemes
#define RED2RED 0
#define GREEN2GREEN 1
#define BLUE2BLUE 2
#define BLUE2RED 3
#define GREEN2RED 4
#define RED2GREEN 5

#define TFT_GREY 0x2104 // Dark grey 16 bit colour


#include "alert.h" // Out of range alert icon

#include <TFT_eSPI.h> // Hardware-specific library
#include <SPI.h>

#include <Wire.h>
#include "Adafruit_SGP30.h"
#include "DHT.h"


#define BUZZPIN 5

#define LDO_PWR_EN_PIN 19   //AP2112K enable pin


#define   BUZZER_ON     digitalWrite(BUZZPIN, HIGH)
#define   BUZZER_OFF   digitalWrite(BUZZPIN, LOW)

#define   LDO_1V8_ON   digitalWrite(LDO_PWR_EN_PIN, HIGH)
#define   LDO_1V8_OFF  digitalWrite(LDO_PWR_EN_PIN, LOW)

#define DHTPIN 18     // Digital pin connected to the DHT sensor
#define DHTTYPE DHT11   // DHT11
DHT dht(DHTPIN, DHTTYPE);


Adafruit_SGP30 sgp;
#define I2C_SDA 26
#define I2C_SCL 27




TFT_eSPI tft = TFT_eSPI(); // Invoke custom library with default width and height

uint32_t runTime = -99999; // time for next update
int d = 0;       // Variable used for the sinewave test waveform
boolean range_error = 0;

unsigned long lastDebounceTime = 0; // the last time the output pin was toggled
unsigned long debounceDelay = 1000; // the debounce time; increase if the output flickers
int CO2_level = 0;
int Count = 0;
int counter = 0;
float humidity = 0;
float temperature = 0;


uint32_t getAbsoluteHumidity(float temperature, float humidity) {
    // approximation formula from Sensirion SGP30 Driver Integration chapter 3.15
    const float absoluteHumidity = 216.7f * ((humidity / 100.0f) * 6.112f * exp((17.62f * temperature) / (243.12f + temperature)) / (273.15f + temperature)); // [g/m^3]
    const uint32_t absoluteHumidityScaled = static_cast<uint32_t>(1000.0f * absoluteHumidity); // [mg/m^3]
    return absoluteHumidityScaled;
}




void setup(void)
{
  Serial.begin(115200);

dht.begin();

    pinMode(BUZZPIN, OUTPUT);
    pinMode(LDO_PWR_EN_PIN, OUTPUT);


    BUZZER_ON;
    LDO_1V8_ON;
    delay(1000);
    BUZZER_OFF;

    
    Wire.begin(I2C_SDA, I2C_SCL);

    Serial.println("SGP30 test");

  if (! sgp.begin()){
    Serial.println("Sensor not found :(");
    while (1);
  }


  tft.begin();
  tft.setRotation(3);
  tft.fillScreen(TFT_BLACK);

  tft.setTextColor(TFT_WHITE, TFT_BLACK);
  tft.drawString("Makerfabs", 10, 10, 2);
  //tft.drawString("CO2 level", 215, 305, 2);
  //tft.drawString("Tem", 100, 95, 2);
  //tft.drawString("Hum", 360, 95, 2);
}

void loop()
{
  co2_level_measure();
  if (millis() - runTime >= 0L)
  { // Execute every TBD ms
    runTime = millis();

    // Test with a slowly changing value from a Sine function
    //d += 4; if (d >= 360) d = 0;

    // Set the the position, gap between meters, and inner radius of the meters
    int xpos = 0, ypos = 5, gap = 4, radius = 52;

    // Draw meter and get back x position of next meter

    // Test with Sine wave function, normally reading will be from a sensor
    //reading = 250 + 250 * sineWave(d+0);
    //xpos = gap + ringMeter(reading, 0, 500, xpos, ypos, radius, "mA", GREEN2RED); // Draw analogue meter

    //reading = 20 + 30 * sineWave(d+60);
    //xpos = gap + ringMeter(reading, -10, 50, xpos, ypos, radius, "degC", BLUE2RED); // Draw analogue meter

    //reading = 50 + 50 * sineWave(d + 120);
    //ringMeter(reading, 0, 100, xpos, ypos, radius, "%RH", BLUE2BLUE); // Draw analogue meter

    // Draw two more larger meters
    //xpos = 20, ypos = 115, gap = 24, radius = 64;

    //reading = 1000 + 150 * sineWave(d + 90);
    //xpos = gap + ringMeter(reading, 850, 1150, xpos, ypos, radius, "mb", BLUE2RED); // Draw analogue meter

    //reading = 15 + 15 * sineWave(d + 150);
    //xpos = gap + ringMeter(reading, 0, 30, xpos, ypos, radius, "Volts", GREEN2GREEN); // Draw analogue meter

    // Draw a large meter
    xpos = 40, ypos = 30, gap = 15, radius = 70;
    // Comment out above meters, then uncomment the next line to show large meter
    ringMeter(CO2_level, 0, 5000, 160, 140, 80, "ppm", GREEN2RED); // Draw analogue meter
    ringMeter((int)temperature, -10, 50, 40, 30, 70, "C", BLUE2RED);
    ringMeter((int)humidity, 0, 100, 300, 30, 70, "RH%", RED2GREEN);
  }
}

// #########################################################################
//  Draw the meter on the screen, returns x coord of righthand side
// #########################################################################
int ringMeter(int value, int vmin, int vmax, int x, int y, int r, const char *units, byte scheme)
{
  // Minimum value of r is about 52 before value text intrudes on ring
  // drawing the text first is an option

  x += r;
  y += r; // Calculate coords of centre of ring

  int w = r / 3; // Width of outer ring is 1/4 of radius

  int angle = 150; // Half the sweep angle of meter (300 degrees)

  int v = map(value, vmin, vmax, -angle, angle); // Map the value to an angle v

  byte seg = 3; // Segments are 3 degrees wide = 100 segments for 300 degrees
  byte inc = 6; // Draw segments every 3 degrees, increase to 6 for segmented ring

  // Variable to save "value" text colour from scheme and set default
  int colour = TFT_BLUE;

  // Draw colour blocks every inc degrees
  for (int i = -angle + inc / 2; i < angle - inc / 2; i += inc)
  {
    // Calculate pair of coordinates for segment start
    float sx = cos((i - 90) * 0.0174532925);
    float sy = sin((i - 90) * 0.0174532925);
    uint16_t x0 = sx * (r - w) + x;
    uint16_t y0 = sy * (r - w) + y;
    uint16_t x1 = sx * r + x;
    uint16_t y1 = sy * r + y;

    // Calculate pair of coordinates for segment end
    float sx2 = cos((i + seg - 90) * 0.0174532925);
    float sy2 = sin((i + seg - 90) * 0.0174532925);
    int x2 = sx2 * (r - w) + x;
    int y2 = sy2 * (r - w) + y;
    int x3 = sx2 * r + x;
    int y3 = sy2 * r + y;
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

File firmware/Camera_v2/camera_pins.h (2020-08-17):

#if defined(CAMERA_MODEL_WROVER_KIT)
#define PWDN_GPIO_NUM    -1
#define RESET_GPIO_NUM   -1
#define XCLK_GPIO_NUM    32//21
#define SIOD_GPIO_NUM    26
#define SIOC_GPIO_NUM    27

#define Y9_GPIO_NUM      35
#define Y8_GPIO_NUM      34
#define Y7_GPIO_NUM      39
#define Y6_GPIO_NUM      36
#define Y5_GPIO_NUM      21//19
#define Y4_GPIO_NUM      19//18
#define Y3_GPIO_NUM       18//5
#define Y2_GPIO_NUM       5//4
#define VSYNC_GPIO_NUM   25
#define HREF_GPIO_NUM    23
#define PCLK_GPIO_NUM    22

#elif defined(CAMERA_MODEL_ESP_EYE)
#define PWDN_GPIO_NUM    -1
#define RESET_GPIO_NUM   -1
#define XCLK_GPIO_NUM    4
#define SIOD_GPIO_NUM    18
#define SIOC_GPIO_NUM    23

#define Y9_GPIO_NUM      36
#define Y8_GPIO_NUM      37
#define Y7_GPIO_NUM      38
#define Y6_GPIO_NUM      39
#define Y5_GPIO_NUM      35
#define Y4_GPIO_NUM      14
#define Y3_GPIO_NUM      13
#define Y2_GPIO_NUM      34
#define VSYNC_GPIO_NUM   5
#define HREF_GPIO_NUM    27
#define PCLK_GPIO_NUM    25

#elif defined(CAMERA_MODEL_M5STACK_PSRAM)
#define PWDN_GPIO_NUM     -1
#define RESET_GPIO_NUM    15
#define XCLK_GPIO_NUM     27
#define SIOD_GPIO_NUM     25
#define SIOC_GPIO_NUM     23

#define Y9_GPIO_NUM       19
#define Y8_GPIO_NUM       36
#define Y7_GPIO_NUM       18
#define Y6_GPIO_NUM       39
#define Y5_GPIO_NUM        5
#define Y4_GPIO_NUM       34
#define Y3_GPIO_NUM       35
#define Y2_GPIO_NUM       32
#define VSYNC_GPIO_NUM    22
#define HREF_GPIO_NUM     26
#define PCLK_GPIO_NUM     21

#elif defined(CAMERA_MODEL_M5STACK_WIDE)
#define PWDN_GPIO_NUM     -1
#define RESET_GPIO_NUM    15
#define XCLK_GPIO_NUM     27
#define SIOD_GPIO_NUM     22
#define SIOC_GPIO_NUM     23

#define Y9_GPIO_NUM       19
#define Y8_GPIO_NUM       36
#define Y7_GPIO_NUM       18
#define Y6_GPIO_NUM       39
#define Y5_GPIO_NUM        5
#define Y4_GPIO_NUM       34
#define Y3_GPIO_NUM       35
#define Y2_GPIO_NUM       32
#define VSYNC_GPIO_NUM    25
#define HREF_GPIO_NUM     26
#define PCLK_GPIO_NUM     21

#elif defined(CAMERA_MODEL_MAKERFABS)
#define PWDN_GPIO_NUM    -1
#define RESET_GPIO_NUM   -1
#define XCLK_GPIO_NUM    32
#define SIOD_GPIO_NUM    26
#define SIOC_GPIO_NUM    27

#define Y9_GPIO_NUM      35
#define Y8_GPIO_NUM      34
#define Y7_GPIO_NUM      39
#define Y6_GPIO_NUM      36
#define Y5_GPIO_NUM      21
#define Y4_GPIO_NUM      19
#define Y3_GPIO_NUM      18
#define Y2_GPIO_NUM      5
#define VSYNC_GPIO_NUM   25
#define HREF_GPIO_NUM    23
#define PCLK_GPIO_NUM    22

#else
#error "Camera model not selected"
#endif

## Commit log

2020-08-14 resistor screen draw
2020-08-14 capacitance screen
2020-08-18 Rebuid touch driver
2020-08-20 a simple camera
2020-09-03 change ILI9488 driver,more faster
2020-09-15 There is a bug with NS2009, fix it.
    [Camera_v2.ino, NS2009.cpp, touch_draw_v2.ino]
2020-09-15 add hardware
    [ESP32 TFT Touch with Camera v1.1.brd, ESP32 TFT Touch with Camera v1.1.sch]
2020-09-25 chang new camera ui
2020-12-28 Add sd_test LCD spi init.
2021-03-18 change SCH to V1.2
    [ESP32 TFT Touch with camera v1.2(3.5'' ili9488).brd, ESP32 TFT Touch with camera v1.2(3.5'' ili9488).sch]
2021-05-21 V5.0 Add Environment Expansion Board
    [ESP32 Touch_Indoor Environment Expansion v1.1.brd, ESP32 Touch_Indoor Environment Expansion v1.1.sch]
2021-10-26 V6.0 Wifi Img Display Demo
    [ESP32 Touch_Indoor Environment Expansion v1.1.brd, ESP32 Touch_Indoor Environment Expansion v1.1.sch]

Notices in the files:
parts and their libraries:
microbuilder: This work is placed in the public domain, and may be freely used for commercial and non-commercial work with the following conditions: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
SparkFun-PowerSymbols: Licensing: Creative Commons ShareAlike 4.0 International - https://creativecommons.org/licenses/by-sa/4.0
